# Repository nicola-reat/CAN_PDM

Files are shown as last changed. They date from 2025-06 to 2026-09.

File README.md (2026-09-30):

# CAN PDM – Power Distribution Module
 
A CAN-controlled power distribution module (PDM) designed for a race car. It replaces fuses, relays and dashboard switches with nine protected, current-monitored high-side outputs that are switched from a Blink Marine keypad over CAN.
 
This repository contains everything needed to understand, build and modify the module: firmware, CAN documentation and DBC files, the Altium PCB project with thermal simulations, and the 3D models of the enclosure and bus bar.
 
| MCU | Supply | Outputs | CAN | Firmware |
|:---:|:---:|:---:|:---:|:---:|
| STM32F446RET6 | 12 V | 9 protected channels | 500 kbit/s | STM32 HAL |
 
## Table of contents
 
1. [What it does](#what-it-does)
2. [System overview](#system-overview)
3. [Outputs](#outputs)
4. [Protection](#protection)
5. [Keypad control](#keypad-control)
6. [On-board LEDs](#on-board-leds)
7. [CAN interface](#can-interface)
8. [Running two boards](#running-two-boards)
9. [Repository structure](#repository-structure)
10. [Hardware](#hardware)
11. [Firmware](#firmware)
---
 
## What it does
 
The PDM sits between the battery and the car's electrical loads: fuel pumps, fans, heating, cabin fans, lights and most other consumers. Each load is fed through its own Infineon PROFET smart high-side switch. The microcontroller switches the outputs, measures the current of every channel, and reacts to faults before wiring or loads are damaged.
 
- **Switches nine outputs** on request, from the keypad or from a CAN command frame.
- **Measures current** on every output, plus battery voltage and board temperature.
- **Detects faults** per channel: overcurrent, short circuit, open load and thermal.
- **Sheds load by priority** when the board gets too hot or the battery voltage drops: low-priority outputs go first, then medium, and everything at the critical level.
- **Gives feedback on the keypad**: each button LED shows whether its output is on or off, and blinks in a fault-specific color when the output has failed.
- **Gives feedback on the board**: nine bicolor LEDs, one per output, show the output state and blink in a fault-specific pattern.
- **Reports everything over CAN**: status, currents and fault codes are transmitted every 100 ms for a dashboard or data logger.
## System overview
 
```mermaid
flowchart LR
    BAT["12 V battery"] --> PDM1["PDM_1"]
    BAT --> PDM2["PDM_2"]
    KP["Blink Marine keypad"] --- CAN(["CAN bus, 500 kbit/s"])
    CAN --- PDM1
    CAN --- PDM2
    CAN --- LOG["Dashboard / logger / SavvyCAN"]
    PDM1 --> LOADS1["Pumps, fans, heating, lights..."]
    PDM2 --> LOADS2["Pumps, fans, heating, lights..."]
```
 
A key press is sent by the keypad to the bus. Every PDM receives it and decides, from its own key-to-output mapping, whether one of its outputs is affected. The PDM then confirms the result by updating the LED on the same key and the output's LED on the board.
 
## Outputs
 
Nine outputs, grouped by current capability. Values below are the limits configured in the firmware. They were set to arbitrary, wide-margin values, and only after several tests. They obviously need to be fine-tuned for the actual load. Next planned feature: configuring these parameters over CAN through a GUI.
 
| Group | Outputs | Device | Continuous limit | Startup limit (duration) | Short-circuit threshold | Open-load threshold | Priority |
|---|:---:|---|:---:|:---:|:---:|:---:|:---:|
| High | H1, H2 | BTS7002-1EPP | 21 A | 81 A (1.5 s) | 50 A | 1.0 A | High |
| High | H3 | BTS7002-1EPP | 21 A | 41 A (1.5 s) | 50 A | 0.5 A | High |
| Medium | M1, M2 | BTS7004-1EPZ | 15 A | 40 A (3.0 s) | 40 A | 0.5 A | Medium |
| Low | L1, L2 | BTS7008-2EPZ | 7.5 A | 25 A (2.5 s) | 25 A | 0.5 A | Low |
| Low | L3, L4 | BTS7008-2EPZ | 7.5 A | 15 A (2.5 s) | 15 A | 0.5 A | Low |
 
- Each output has its own continuous limit, a higher startup limit for a set time (loads such as lamps, motors and pumps draw a large inrush current), a short-circuit threshold and an open-load threshold.
- The BTS7008-2EPZ is a dual-channel device: **L1/L2 share one current-sense line and L3/L4 share another**.
- Load current is measured from the PROFET current-sense output: the ADC reads the voltage across a 1.2 kΩ sense resistor, `IIS = V / Rsense`, and the load current is `Iload = IIS × kILIS`, where kILIS is the device's current-sense ratio.
## Protection
 
### Per-channel faults
 
Current-based monitoring runs only while an output is on. While an output is off its current reading is ignored, so ADC noise cannot cause false faults.
 
| Fault | Condition | Result |
|---|---|---|
| Short circuit | Current stays above the short-circuit threshold for at least 50 ms | Output switched off, fault latched |
| Overcurrent | Current exceeds the active limit: the startup limit during the startup time, the continuous limit afterwards | Output switched off immediately, fault latched |
| Open load | Current stays below the open-load threshold for at least 200 ms, checked starting 500 ms after switch-on | Fault reported, output stays on, cleared automatically when the current rises above the threshold |
| Thermal | Thermal fault on the channel | Latched, like short circuit and overcurrent |
 
**Latched faults.** Short circuit, overcurrent and thermal faults are hard faults: the output cannot be switched on again until the fault is reset. Pressing the output's key on the keypad resets the fault and requests the output on. If the cause is still present, the fault is detected again and the output stays faulted until the next reset. Open load is the exception: it is not latched, and it clears by itself once the load draws current again.
 
Faults are shown on the keypad (blinking LED) and reported in the CAN fault messages.
 
### Over-temperature (board temperature)
 
| Level | Threshold | Action | Recovery |
|---|:---:|---|:---:|
| Warning | 70 °C | Reports the `OVERTEMP` state only | – |
| Low priority | 85 °C | Low-priority outputs switched off | 80 °C |
| Medium priority | 95 °C | Medium-priority outputs switched off | 90 °C |
| Critical | 100 °C | All outputs switched off | 95 °C |
 
### Under-voltage (battery voltage)
 
| Level | Threshold | Action | Recovery |
|---|:---:|---|:---:|
| Warning | 11.8 V | Reports the `UNDERVOLTAGE` state only | – |
| Low priority | 11.5 V | Low-priority outputs switched off | 12.0 V |
| Medium priority | 11.2 V | Medium-priority outputs switched off | 11.8 V |
| Critical | 9.5 V | All outputs switched off | 10.5 V |
 
Every level has a **hysteresis**: the recovery threshold is different from the shutdown threshold, so outputs do not turn on and off repeatedly around a limit.
 
- Outputs shed by a thermal or under-voltage shutdown come back **automatically** once the temperature or voltage passes the recovery threshold, as long as they are still requested on.
- The warning levels only change the state reported over CAN. They do not switch anything off. If both warnings are active, `OVERTEMP` takes precedence over `UNDERVOLTAGE`.
- Outputs in a latched fault (see above) are always kept off.
- Priorities are ordered High (1), Medium (2), Low (3). Each shutdown level switches off its own priority and every less important one, so **High-priority outputs are only switched off at the critical level**.
## Keypad control
 
The PDM works with a **Blink Marine CAN keypad**. Each button is associated with one output:
 
- Press a button to **toggle** its output.
- If the output is in fault, pressing the button **resets the fault** and switches the output on again.
- The LED shows the output state: green when on, off when off, and blinking yellow, amber, red or cyan for open load, overcurrent, short circuit and thermal faults.
- The LED state is re-sent every 100 ms, so the keypad recovers if a CAN frame is lost.
- Keypad brightness is set by the PDM at startup.
The key-to-output mapping is different for each board and is listed in the CAN documentation.
 
## On-board LEDs
 
Each output has a bicolor (green/red) LED on the PCB, so its state can be read at a glance without a keypad or a CAN tool. Together with the keypad LEDs and the CAN messages, there are three ways to see what an output is doing.
 
| LED | Meaning |
|---|---|
| Both off | Output off |
| Green, steady | Output on, no fault |
| Red, blinking | Fault on this output (green is off) |
 
The number of red blinks tells which fault it is. The sequence is followed by a one-second pause and then repeats.
 
| Red blinks | Fault |
|:---:|---|
| 1 | Open load |
| 2 | Overcurrent |
| 3 | Short circuit |
| 4 | Thermal |
| 5 | Under-voltage |
 
Example: two blinks, pause, two blinks, pause... means overcurrent.
 
## CAN interface
 
| Parameter | Value |
|---|---|
| Bitrate | 500 kbit/s |
| Status messages | Every 100 ms |
| Byte order | Little-endian |
| Units | A, V, °C |
 
Transmitted messages: PDM status (heartbeat, state, total current, battery voltage, temperature), status and current of every output group, and fault codes for every output. Received messages: the output command and the keypad key frames.
 
The complete reference, with byte layouts and conversion formulas, is in [`FW/Doc/`](FW/Doc/). Ready-to-use DBC files for [SavvyCAN](https://www.savvycan.com/) are in [`FW/Dbc_Database/`](FW/Dbc_Database/).
 
## Running two boards
 
The car uses **two identical PDM boards**. They are not different hardware: `PDM_ID` in the firmware gives each board its own identity.
 
| | PDM_1 | PDM_2 |
|---|:---:|:---:|
| CAN address | `0x30` | `0x31` |
| Status message ID | `0x300` | `0x400` |
| Output messages | `0x301`–`0x313` | `0x401`–`0x413` |
| Command frame | `0x200` | `0x200` |
 
Both boards share the same bus and receive the same keypad frames; each applies its own key-to-output mapping.
 
## Repository structure
 
```
.
├── 3D/                  3D models: bus bar, cover and case
├── Docs/                Pinout of PDM_1 and PDM_2 as installed in the car
├── FW/
│   ├── Doc/             CAN message documentation
│   ├── Dbc_Database/    DBC files for SavvyCAN (one per board)
│   └── can_pdm/         Firmware project
└── PCB/
    ├── 3d/              STEP model of the PCB
    ├── CAN_PDM/         Altium Designer project
    └── thermal analysis/ Thermal simulations
```
 
## Hardware
 
- **PCB:** designed in Altium Designer, project in `PCB/CAN_PDM/`. A STEP model of the assembled board is in `PCB/3d/`.
- **Status LEDs:** nine bicolor LEDs, one per output, driven through a PCAL6524 I/O expander.
- **Thermal analysis:** simulations of the board under load are in `PCB/thermal analysis/`.
- **Mechanical parts:** bus bar, case and cover models are in `3D/`.
- **Pinout:** the current pinout of both boards, as installed in the car, is in `Docs/`.
## Firmware
 
- Microcontroller: **STM32F446RET6**
- Framework: STM32 HAL, CAN1 at 500 kbit/s
- Toolchain: **STM32CubeIDE**. Open `FW/can_pdm/` as a project, build and flash from the IDE.
- Project: `FW/can_pdm/`
- Board selection: set `PDM_ID` (`PDM_1` or `PDM_2`) in the firmware configuration before building. Each board must be flashed with its own identity.
- Protection thresholds (temperature, voltage) and per-channel current limits are defined in `pdm_config`, and can be changed there.
The firmware runs on FreeRTOS with three tasks:
 
| Task | Period | Job |
|---|:---:|---|
| Acquisition | 10 ms | Reads the battery voltage (ADC) and the board temperature (MCP9808 sensor), updates the current of all nine outputs and runs the fault checks |
| Telemetry | 100 ms | Transmits all CAN status, current and fault messages, and updates the keypad LEDs |
| Power manager | 100 ms | Applies the thermal and under-voltage protection, applies the requested state to every output and sets the PDM state |
 
PDM state reported in the CAN status message:
 
| State | When |
|---|---|
| `RUN` | Normal operation |
| `UNDERVOLTAGE` | Battery voltage below 11.8 V |
| `OVERTEMP` | Board temperature above 70 °C (takes precedence over `UNDERVOLTAGE`) |
| `INIT` | Initial value at power-up |
| `FAULT`, `SLEEP` | Defined in the firmware but not set by the power manager |
 
## License
 
This project is open source and released under the [MIT License](LICENSE). You are free to use, modify and share it, as long as the copyright notice is kept.
 
This hardware and firmware control high-current circuits in a vehicle. It is provided as is, with no warranty: build and install it at your own risk.

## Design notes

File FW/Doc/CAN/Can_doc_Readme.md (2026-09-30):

# CAN PDM – CAN Bus Message Reference

Reference for every CAN message received and transmitted by the PDM (Power Distribution Module), including byte layouts and the formulas needed to convert raw hexadecimal data into units (Amperes, Volts, °C).

| Bitrate | Cycle time | Frame length | Byte order | Units |
|:---:|:---:|:---:|:---:|:---:|
| **500 kbit/s** | **100 ms** | **DLC 8** | **Little-endian** | °C · V · A |

## Table of contents

1. [Overview](#1-overview)
2. [How to decode a value](#2-how-to-decode-a-value)
3. [Message list and IDs](#3-message-list-and-ids)
4. [Enumerations](#4-enumerations)
5. [Received messages](#5-received-messages)
6. [Transmitted messages](#6-transmitted-messages)
7. [Blink Marine keypad](#7-blink-marine-keypad)

---

## 1. Overview

The PDM drives nine Profet output channels, grouped by current capability:

| Group | Channels |
|---|---|
| High | H1, H2, H3 |
| Medium | M1, M2 |
| Low | L1, L2, L3, L4 |

Outputs can be switched:

- by a **Blink Marine keypad** (extended CAN frames), or
- by the **`0x200` command frame** (standard CAN frame) Only for bench-testing.

The PDM periodically transmits its own status, per-output currents and fault codes.

**Multiple boards on one bus.** `PDM_1` and `PDM_2` are not different hardware: they are two identical boards installed in the same vehicle. `PDM_ID` is set at compile time to give each board its own identity (CAN address and status IDs), so both can share one bus. The command frame `0x200` uses the same ID on both boards [To Be deleted].

**Legend used in the byte tables**

| Symbol | Meaning |
|:---:|---|
| ⬜ | Counter / heartbeat |
| 🟧 | State or flags |
| 🟩 | Current (A) |
| 🟪 | Voltage (V) |
| 🟥 | Temperature (°C) |
| 🟦 | Output number or key number |
| ⬛ | Reserved / unused |

---

## 2. How to decode a value

16-bit values are sent **LSB first**:

```
value = LSB + (MSB × 256)
```

Then apply the scale factor of the field:

| Quantity | Formula | Resolution |
|---|---|---|
| Current | `value / 10` → A | 0.1 A |
| Battery voltage | `value / 100` → V | 0.01 V |
| Temperature | `value / 100` → °C | 0.01 °C |

Example: bytes `64 00` → `0x0064` = 100 → 100 / 10 = **10.0 A**.

---

## 3. Message list and IDs

Each board takes its identity (`PDM_1` or `PDM_2`) from `PDM_ID`. CAN addresses used for the extended frames:

| Device | CAN address |
|---|:---:|
| Keypad (`KEYPAD_CAN_ADDRESS`) | `0x21` |
| PDM_1 (`PDM_CAN_ADDRESS`) | `0x30` |
| PDM_2 (`PDM_CAN_ADDRESS`) | `0x31` |

### Standard frames (11-bit ID)

| Message | Direction | PDM_1 | PDM_2 | Section |
|---|:---:|:---:|:---:|:---:|
| Output command | RX | `0x200` | `0x200` | [5.1](#51-output-command--0x200) |
| PDM status | TX | `0x300` | `0x400` | [6.1](#61-pdm-status--0x300--0x400) |
| High outputs fault types (H1–H3) | TX | `0x301` | `0x401` | [6.3](#63-fault-types) |
| Medium outputs fault types (M1–M2) | TX | `0x302` | `0x402` | [6.3](#63-fault-types) |
| Low 1 outputs fault types (L1–L2) | TX | `0x303` | `0x403` | [6.3](#63-fault-types) |
| Low 2 outputs fault types (L3–L4) | TX | `0x304` | `0x404` | [6.3](#63-fault-types) |
| High outputs status and currents | TX | `0x310` | `0x410` | [6.2](#62-output-status-and-currents) |
| Medium outputs status and currents | TX | `0x311` | `0x411` | [6.2](#62-output-status-and-currents) |
| Low 1 outputs status and currents | TX | `0x312` | `0x412` | [6.2](#62-output-status-and-currents) |
| Low 2 outputs status and currents | TX | `0x313` | `0x413` | [6.2](#62-output-status-and-currents) |

### Extended frames (29-bit ID, keypad)

| Message | Direction | PDM_1 | PDM_2 | Section |
|---|:---:|:---:|:---:|:---:|
| Key press from keypad | RX | `0x18EFFF21` | `0x18EFFF21` | [7.1](#71-key-press-keypad--pdm) |
| LED command to keypad | TX | `0x18EF2130` | `0x18EF2131` | [7.3](#73-led-command-pdm--keypad) |
| Brightness command to keypad | TX | `0x18EF2130` | `0x18EF2131` | [7.4](#74-brightness-command-pdm--keypad) |

Extended ID format: `0x18EF` + destination address + source address.

> Received frames reach **both** PDMs at the same time. Each PDM interprets them with its own rules: for the keypad, with its own key-to-output mapping ([7.2](#72-key-to-output-mapping)).

---

## 4. Enumerations

### 4.1 Output number (`PDM_Output_t`)

| Value | Output | Group |
|:---:|:---:|---|
| 1 | H1 | High |
| 2 | H2 | High |
| 3 | H3 | High |
| 4 | M1 | Medium |
| 5 | M2 | Medium |
| 6 | L1 | Low |
| 7 | L2 | Low |
| 8 | L3 | Low |
| 9 | L4 | Low |

### 4.2 PDM state (`PDM_State_t`)

| Value | State |
|:---:|---|
| 0 | `PDM_STATE_INIT` |
| 1 | `PDM_STATE_RUN` |
| 2 | `PDM_STATE_FAULT` |
| 3 | `PDM_STATE_OVERTEMP` |
| 4 | `PDM_STATE_UNDERVOLTAGE` |
| 5 | `PDM_STATE_SLEEP` |

### 4.3 Fault type (`ProfetFault_t`)

| Value | Fault | Keypad LED |
|:---:|---|---|
| 0 | `FAULT_NONE` | Follows output state |
| 1 | `FAULT_OVERCURRENT` | Amber/orange, blinking |
| 2 | `FAULT_SHORT_CIRCUIT` | Red, blinking |
| 3 | `FAULT_OPEN_LOAD` | Yellow, blinking |
| 4 | `FAULT_THERMAL` | Cyan, blinking |
| 5 | `FAULT_UNDERVOLTAGE` | No dedicated LED rule |

### 4.4 Keypad LED colors (`KeypadLedColor_t`)

| Value | Color |
|:---:|---|
| `0x00` | Off |
| `0x01` | Red |
| `0x02` | Green |
| `0x03` | Blue |
| `0x04` | Yellow |
| `0x05` | Magenta |
| `0x06` | Cyan |
| `0x07` | White |
| `0x08` | Amber / orange |

### 4.5 Keypad LED modes (`KeypadLedMode_t`)

| Value | Mode |
|:---:|---|
| `0x00` | Off |
| `0x01` | On (steady) |
| `0x02` | Blinking |

---

## 5. Received messages

### 5.1 Output command – `0x200`

Standard frame. Requests an output to be switched on or off.

| Byte 0 | Byte 1 | Byte 2 | Byte 3 | Byte 4 | Byte 5 | Byte 6 | Byte 7 |
|:---:|:---:|:---:|:---:|:---:|:---:|:---:|:---:|
| 🟦 Output | 🟧 State | ⬛ | ⬛ | ⬛ | ⬛ | ⬛ | ⬛ |

| Field | Values |
|---|---|
| Output | 1–9, see [4.1](#41-output-number-pdm_output_t) |
| State | `0` = off, any non-zero value = on |

The PDM does not switch the output directly: it sets the channel's requested state, and the protection logic decides whether to enable it.

Examples:

| Frame data | Effect |
|---|---|
| `01 01 00 00 00 00 00 00` | Turn H1 on |
| `06 00 00 00 00 00 00 00` | Turn L1 off |

> In the firmware, PDM_1 and PDM_2 handle this frame identically (same output numbering, no PDM address check).

The keypad frame `0x18EFFF21` is described in [7.1](#71-key-press-keypad--pdm).

---

## 6. Transmitted messages

All messages below are sent every **100 ms**, DLC 8, little-endian.

### 6.1 PDM status – `0x300` / `0x400`

| Byte 0 | Byte 1 | Byte 2 | Byte 3 | Byte 4 | Byte 5 | Byte 6 | Byte 7 |
|:---:|:---:|:---:|:---:|:---:|:---:|:---:|:---:|
| ⬜ Alive | 🟧 State | 🟩 Current LSB | 🟩 Current MSB | 🟪 Voltage LSB | 🟪 Voltage MSB | 🟥 Temp LSB | 🟥 Temp MSB |

| Bytes | Field | Type | Conversion |
|:---:|---|---|---|
| 0 | Alive heartbeat | `uint8` | Counter, increments each message (0–255, then wraps) |
| 1 | PDM state | `uint8` | See [4.2](#42-pdm-state-pdm_state_t) |
| 2–3 | Total current | `uint16` | `value / 10` → **A** |
| 4–5 | Battery voltage | `uint16` | `value / 100` → **V** |
| 6–7 | PDM temperature | `uint16` | `value / 100` → **°C** |

**Example:** `2A 01 64 00 14 05 C4 09`

| Field | Raw | Result |
|---|:---:|---|
| Heartbeat | `0x2A` | 42 |
| State | `0x01` | RUN |
| Total current | `0x0064` = 100 | **10.0 A** |
| Battery voltage | `0x0514` = 1300 | **13.00 V** |
| Temperature | `0x09C4` = 2500 | **25.00 °C** |

### 6.2 Output status and currents

One message per output group. Byte 0 holds status bits, followed by one 16-bit current per output (`value / 10` → **A**).

#### High outputs – `0x310` / `0x410`

| Byte 0 | Byte 1 | Byte 2 | Byte 3 | Byte 4 | Byte 5 | Byte 6 | Byte 7 |
|:---:|:---:|:---:|:---:|:---:|:---:|:---:|:---:|
| 🟧 Flags | 🟩 H1 LSB | 🟩 H1 MSB | 🟩 H2 LSB | 🟩 H2 MSB | 🟩 H3 LSB | 🟩 H3 MSB | ⬛ |

| Bit | Meaning |
|:---:|---|
| 0 | H1 enabled |
| 1 | H2 enabled |
| 2 | H3 enabled |
| 3 | H1 fault |
| 4 | H2 fault |
| 5 | H3 fault |
| 6–7 | Unused |

#### Medium outputs – `0x311` / `0x411`

| Byte 0 | Byte 1 | Byte 2 | Byte 3 | Byte 4 | Byte 5 | Byte 6 | Byte 7 |
|:---:|:---:|:---:|:---:|:---:|:---:|:---:|:---:|
| 🟧 Flags | 🟩 M1 LSB | 🟩 M1 MSB | 🟩 M2 LSB | 🟩 M2 MSB | ⬛ | ⬛ | ⬛ |

| Bit | Meaning |
|:---:|---|
| 0 | M1 enabled |
| 1 | M2 enabled |
| 2 | M1 fault |
| 3 | M2 fault |
| 4–7 | Unused |

#### Low 1 outputs – `0x312` / `0x412`

| Byte 0 | Byte 1 | Byte 2 | Byte 3 | Byte 4 | Byte 5 | Byte 6 | Byte 7 |
|:---:|:---:|:---:|:---:|:---:|:---:|:---:|:---:|
| 🟧 Flags | 🟩 L1 LSB | 🟩 L1 MSB | 🟩 L2 LSB | 🟩 L2 MSB | ⬛ | ⬛ | ⬛ |

| Bit | Meaning |
|:---:|---|
| 0 | L1 enabled |
| 1 | L2 enabled |
| 2 | L1 fault |
| 3 | L2 fault |
| 4–7 | Unused |

#### Low 2 outputs – `0x313` / `0x413`

| Byte 0 | Byte 1 | Byte 2 | Byte 3 | Byte 4 | Byte 5 | Byte 6 | Byte 7 |
|:---:|:---:|:---:|:---:|:---:|:---:|:---:|:---:|
| 🟧 Flags | 🟩 L3 LSB | 🟩 L3 MSB | 🟩 L4 LSB | 🟩 L4 MSB | ⬛ | ⬛ | ⬛ |

| Bit | Meaning |
|:---:|---|
| 0 | L3 enabled |
| 1 | L4 enabled |
| 2 | L3 fault |
| 3 | L4 fault |
| 4–7 | Unused |

The **fault bit** is set when the channel's fault type is anything other than `FAULT_NONE`. The exact fault is reported in the fault messages ([6.3](#63-fault-types)).

**Example** – ID `0x310`, data `03 2C 01 00 00 00 00 00`:

| Field | Raw | Result |
|---|:---:|---|
| Flags | `0x03` | H1 and H2 enabled, no fault |
| H1 current | `0x012C` = 300 | **30.0 A** |
| H2 current | `0x0000` | **0.0 A** |
| H3 current | `0x0000` | **0.0 A** |

### 6.3 Fault types

One byte per output, containing the fault code from [4.3](#43-fault-type-profetfault_t). Unused bytes are `0`.

| ID (PDM_1) | ID (PDM_2) | Byte 0 | Byte 1 | Byte 2 | Bytes 3–7 |
|:---:|:---:|:---:|:---:|:---:|:---:|
| `0x301` | `0x401` | H1 | H2 | H3 | 0 |
| `0x302` | `0x402` | M1 | M2 | 0 | 0 |
| `0x303` | `0x403` | L1 | L2 | 0 | 0 |
| `0x304` | `0x404` | L3 | L4 | 0 | 0 |

**Example** – ID `0x301`, data `00 03 00 00 00 00 00 00`: H2 reports `FAULT_OPEN_LOAD`; H1 and H3 have no fault.

---

## 7. Blink Marine keypad

The keypad uses J1939-style extended frames (`0x18EF` + destination + source), addresses listed in [section 3](#3-message-list-and-ids).

### 7.1 Key press (keypad → PDM)

**ID `0x18EFFF21`** – destination `0xFF` (broadcast), source `0x21` (keypad). Received by both PDMs.

| Byte 0 | Byte 1 | Byte 2 | Byte 3 | Byte 4 | Byte 5 | Byte 6 | Byte 7 |
|:---:|:---:|:---:|:---:|:---:|:---:|:---:|:---:|
| ⬛ | ⬛ | ⬛ | 🟦 Key number | 🟧 Pressed | ⬛ | ⬛ | ⬛ |

| Field | Values |
|---|---|
| Key number | Key ID, see mapping below |
| Pressed | `1` = pressed, `0` = released |

Behavior on a **press edge**:

- If the associated output is in fault → the fault is reset and the output is requested **on**.
- Otherwise → the output **toggles** (on ↔ off).

### 7.2 Key-to-output mapping

Each PDM uses its own mapping. `30` is a placeholder meaning "no key assigned".

| Output | PDM_1 key | PDM_2 key |
|:---:|:---:|:---:|
| H1 | 8 | 6 |
| H2 | 14 | 7 |
| H3 | 10 | 30 (unassigned) |
| M1 | 3 | 13 |
| M2 | 2 | 30 (unassigned) |
| L1 | 1 | 1 |
| L2 | 30 (unassigned) | 5 |
| L3 | 30 (unassigned) | 30 (unassigned) |
| L4 | 30 (unassigned) | 30 (unassigned) |

> ⚠️ If the keypad has a real key numbered 30, pressing it would toggle **all** outputs mapped to 30 at the same time.

### 7.3 LED command (PDM → keypad)

**ID** `0x18EF0000 | (KEYPAD_CAN_ADDRESS << 8) | PDM_CAN_ADDRESS`

| PDM | ID |
|:---:|:---:|
| PDM_1 | `0x18EF2130` |
| PDM_2 | `0x18EF2131` |

| Byte 0 | Byte 1 | Byte 2 | Byte 3 | Byte 4 | Byte 5 | Byte 6 | Byte 7 |
|:---:|:---:|:---:|:---:|:---:|:---:|:---:|:---:|
| `0x04` | `0x1B` | `0x01` | 🟦 Key number | 🟩 Color | 🟪 Mode | `0xFF` | `0xFF` |

Colors: see [4.4](#44-keypad-led-colors-keypadledcolor_t). Modes: see [4.5](#45-keypad-led-modes-keypadledmode_t).

LED behavior, in priority order:

| Condition | Color | Mode |
|---|---|---|
| `FAULT_OPEN_LOAD` | Yellow | Blinking |
| `FAULT_OVERCURRENT` | Amber / orange | Blinking |
| `FAULT_SHORT_CIRCUIT` | Red | Blinking |
| `FAULT_THERMAL` | Cyan | Blinking |
| Output enabled | Green | On |
| Output disabled | Green | Off |

The command is sent when the LED state or mode changes, and **re-sent every 100 ms** otherwise, so the keypad recovers if a frame is lost.

### 7.4 Brightness command (PDM → keypad)

Same ID as the LED command.

| Byte 0 | Byte 1 | Byte 2 | Byte 3 | Byte 4 | Byte 5 | Byte 6 | Byte 7 |
|:---:|:---:|:---:|:---:|:---:|:---:|:---:|:---:|
| `0x04` | `0x1B` | `0x02` | 🟧 Brightness | `0xFF` | `0xFF` | `0xFF` | `0xFF` |

Brightness byte = `percent × 63 / 100` (0 % → `0x00`, 100 % → `0x3F`). The PDM sets 100 % at startup.

---

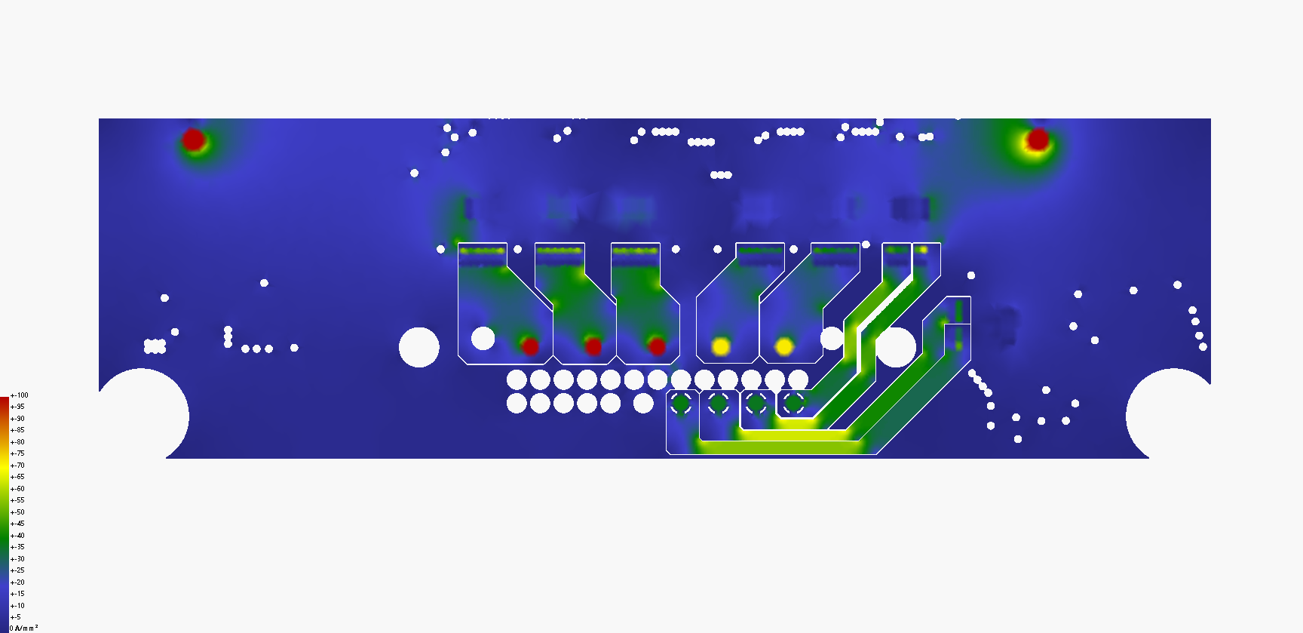
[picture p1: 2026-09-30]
PCB/Thermal_analysis/DC_DROP_CURRENT_DENSITY_BOTTOM.png

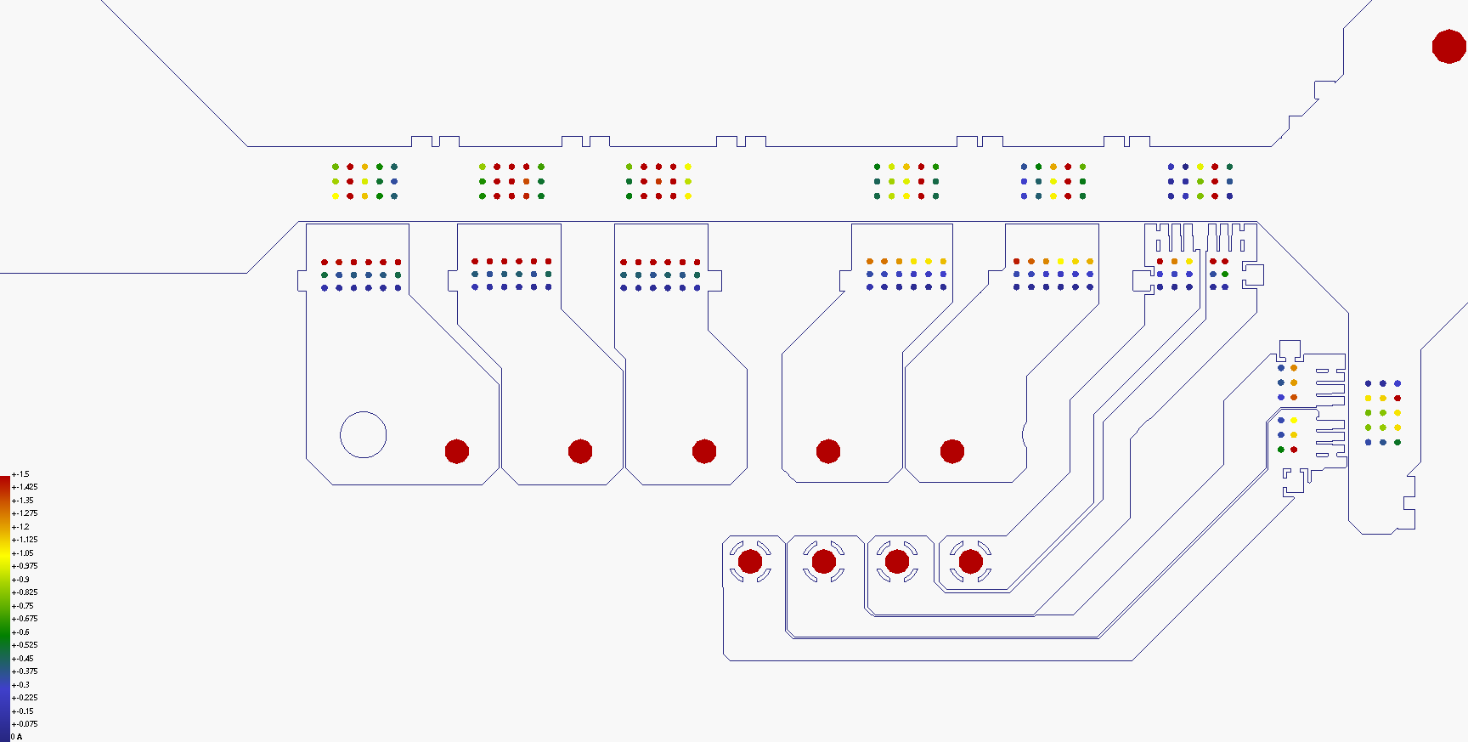
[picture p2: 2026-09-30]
PCB/Thermal_analysis/DC_DROP_VIA_CURRENT.png

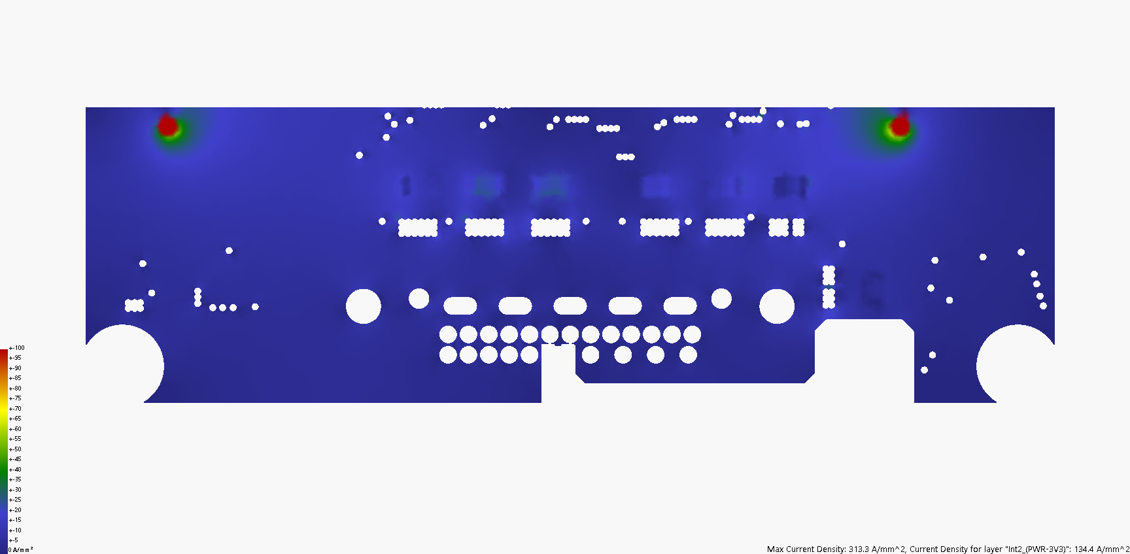
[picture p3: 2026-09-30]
PCB/Thermal_analysis/DC_DROP_CURRENT_DENSITY_IN.png

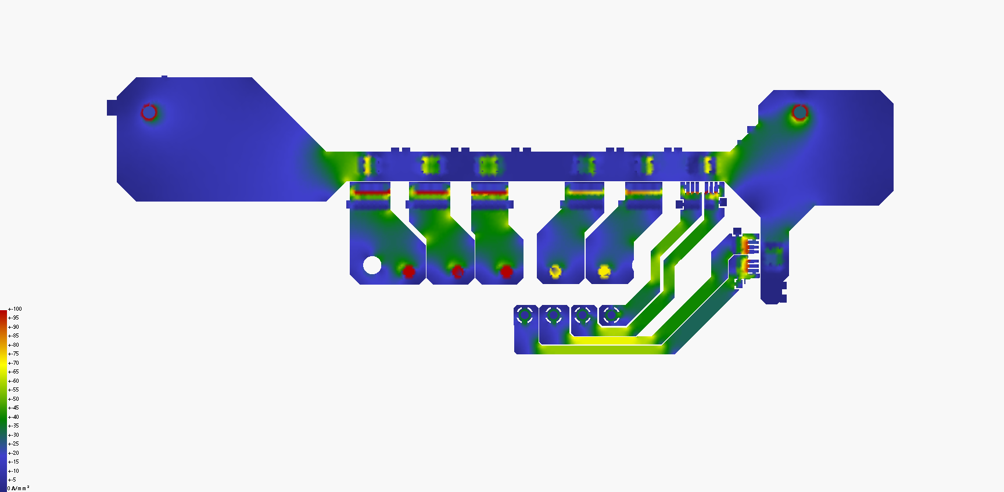
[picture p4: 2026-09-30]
PCB/Thermal_analysis/DC_DROP_CURRENT_DENSITY_TOP.png

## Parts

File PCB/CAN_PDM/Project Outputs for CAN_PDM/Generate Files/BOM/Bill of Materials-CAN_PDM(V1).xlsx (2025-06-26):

 | Bill of Materials |  |  | NR DEVS
Project Title: | Bill of Materials for Variant [V1] of Project [CAN_PDM.PrjPcb] (No PCB Document Selected)
Project File Name: | CAN_PDM.PrjPcb
Assembly Variant: | V1
Designator | Manufacturer | Manufacture Part Number | Footprint | PART-DB Part Number | Quantity
Designator | Manufacturer | PartNumber | Footprint |  | Quantity
C1 | KEMET | C1206C225K5RAC | CAPC3216X16M |  | 1
C2, C10, C12, C14, C16, C17, C21, C23, C24, C25, C27, C28, C30, C34, C38, C42, C47, C48, C51, C52, C57, C58, C62, C67, C72 | KEMET | C0603C104K5RACTU | CAPC1608X09M |  | 25
C3, C4, C5, C6, C9, C11, C13, C15 | Samsung Electro-Mechanics | CL31B106KBHNNNE | CAPC3216X16M |  | 8
C7, C8, C18, C59, C60 | KEMET | C0603C105K8RACTU | CAPC1608X09M |  | 5
C19, C20 | YAGEO | CC0603FRNPO0BN270 | CAPC1608X09M |  | 2
C22 | KEMET | C1206C475K5RACTU | CAPC2012X14N |  | 1
C26 | YAGEO | CC0603KRX7R9BB473 | CAPC1608X09M |  | 1
C29, C33, C37, C41, C61, C66, C71 | KEMET | C0603C473M5RACTU | CAPC1608X09M |  | 7
C31, C35, C39, C43, C63, C64, C68, C69, C73 | KEMET | C0603C103M5RACTM | CAPC1608X09M |  | 9
C32, C36, C40, C44, C65, C70, C74 | KEMET | C0603C221J5RACTU | CAPC1608X09M |  | 7
C53, C54, C55, C56 | KEMET | C0603C103K1RACTU | CAPC1608X09M |  | 4
D1, D2 | Nexperia | PMEG4010EGWX | SODFL360X130-2M -AC |  | 2
D3 | Littelfuse | SZ1SMB20CAT3G | ONSC-SMB-2 |  | 1
D4, D6, D7, D8, D9, D11, D12, D14 | Nexperia | BZX84W-C4V7-QX | SOT65P210X100-3N - AC |  | 8
D5, D13 | Littelfuse | SM712-02HTG | SOT95P240X120-3N |  | 2
D10 | Littelfuse | SP0504BAHTG | SOT95P280X145-5N |  | 1
DL1, DL2 | Wurth Elektronik | 150060GS75000 | LED0603 |  | 2
DL3 | Wurth Elektronik | 150060BS75000 | LED0603 |  | 1
DL4, DL6 | Wurth | 150141YB73100 | WURTH-SBTW_3528 |  | 2
DL5 | Wurth Elektronik | 150060RS75000 | LED0603 |  | 1
DL7, DL8, DL9, DL10, DL11, DL12, DL13, DL14, DL15 | Wurth | 150141RV73100 | WURTH-SBTW_3528 |  | 9
DL16, DL17, DL18, DL19 | Wurth Elektronik | 150060BS55040 | LED0603 |  | 4
J1 | Samtech | FTSH-105-01-L-DV-007-K | SAMTEC_FTSH-105-X-X-DV-007-P-X |  | 1
J2 | Molex | 477450100 | MOLEX_0477450100 |  | 1
J3 | GCT | USB4105-GF-A | GCT-USB4105-GF-A |  | 1
L1 | BOURNS | SDE0805A-180M | BOURNS_SDE0805A |  | 1
L2 | TDK | MMZ1608R601ATD25 | INDC1608X09N |  | 1
L3, L4 | Murata | BLM18HB331SN1D | INDC1608X09N |  | 2
MP1, MP2 | Wurth Electronics | 74651195R | WURTH_74651195 |  | 2
R1 | Vishay | CRCW060388K7FKEAC | RESC1608X06M |  | 1
R2, R16, R17, R100, R101, R124, R125, R126, R127, R128, R129, R130, R131, R132, R133, R134, R135, R136, R137, R138, R139, R140, R141 | Vishay | RC0603FR-071K3L | RESC1608X06M |  | 23
R3, R4, R9, R14, R15, R18, R19, R32, R33, R46, R47, R58, R59, R62, R63, R74, R75, R78, R79, R86, R87, R102, R103, R104, R113, R114, R115, R152 | YAGEO | AC0603FR-0710KL | RESC1608X06M |  | 28
R5 | Vishay | CRCW060322K1FKEA | RESC1608X06M |  | 1
R6, R8, R99, R142, R143, R144, R145 | Vishay | RC0603FR-07560RL | RESC1608X06M |  | 7
R7, R11, R54, R55, R70, R71, R146, R147 | YAGEO | RC0603JR-070RL | RESC1608X06M |  | 8
R10 | Vishay | CRCW060351K0FKEA | RESC1608X06M |  | 1
R12 | Vishay | CRCW06037K50FKEA | RESC1608X06M |  | 1
R13 | Vishay | CRCW0603120RFKEA | RESC1608X06M |  | 1
R20, R26, R34, R40, R105, R116, R153 | Vishay | CRCW080547R0FKEA | RESC2012X06N |  | 7
R21, R22, R23, R24, R27, R28, R29, R30, R35, R36, R37, R38, R41, R42, R43, R44, R80, R81, R82, R83, R88, R89, R90, R91, R106, R107, R108, R109, R110, R111, R117, R118, R119, R120, R121, R122, R154, R155, R156, R157 | YAGEO | RC0603FR-074K7L | RESC1608X06M |  | 40
R25, R31, R39, R45, R112, R123, R158 | Vishay | CRCW06031K20FKEA | RESC1608X06M |  | 7
R52, R53, R56, R57, R68, R69, R72, R73 | Vishay | CRCW060315K0FKEC | RESC1608X06M |  | 8
R94, R95 | Vishay | CRCW06034K70FKEB | RESC1608X06M |  | 2
R96, R97 | Vishay | CRCW060310K0FKEA | RESC1608X06M |  | 2
R98 | Vishay | CRCW06030000Z0EAC | RESC1608X06M |  | 1
R148, R149, R150, R151 | Vishay | CRCW06035K10FKEC | RESC1608X06M |  | 4
SW1 | Nidec Components | CJS-1200TA | SW_CJS-1200TA |  | 1
TP1, TP2, TP3, TP4, TP5, TP6, TP7, TP8, TP9, TP12, TP13, TP14, TP15, TP16, TP19, TP20, TP21, TP22, TP24 |  |  | TP_c200 |  | 19
U1 | Texas Instruments | LV3842XDBVR | SOT95P280X145-6N |  | 1
U2 | Texas Instruments | TLV75533PDBVR | SOT95P280X145-5N |  | 1
U3 | ST | STM32F446RET6 | STM-LQFP64_M |  | 1
U4 | NXP Semiconductors | TJA1051TK/3,118 | SON65P300X300X100-9N-D |  | 1
U5, U6, U18 | Infineon Technologies | BTS70021EPPXUMA1 | SOP65P600X115-15 |  | 3
U7, U8 | Infineon Technologies | BTS70041EPZXUMA1 | SOP65P600X115-15 |  | 2
U9, U10, U11, U12 | Texas Instrument | TLV9001IDBVR | SOT95P280X145-5N |  | 4
U13 | Infineon Technologies | FM24CL16B-GTR | SOIC127P600X175-8N |  | 1
U14 | NXP Semiconductors | PCAL6524HEAZ | FP-SOT1426-1-IPC_A |  | 1
U15 | Microchip | MCP9808-E/MS | MCHP-MSOP-MS8_N |  | 1
U16 | Infineon Technologies | BTS70082EPZXUMA1 | SOP65P600X115-15 |  | 1
U17 | Infineon Technologies | BTS70802EPAXUMA1 | SOP65P600X115-15 |  | 1
X1 | Abracom | ABM8AIG-8.000MHZ-1Z-T | ABM8G_abracon |  | 1
 |  |  |  |  | 293
Notes

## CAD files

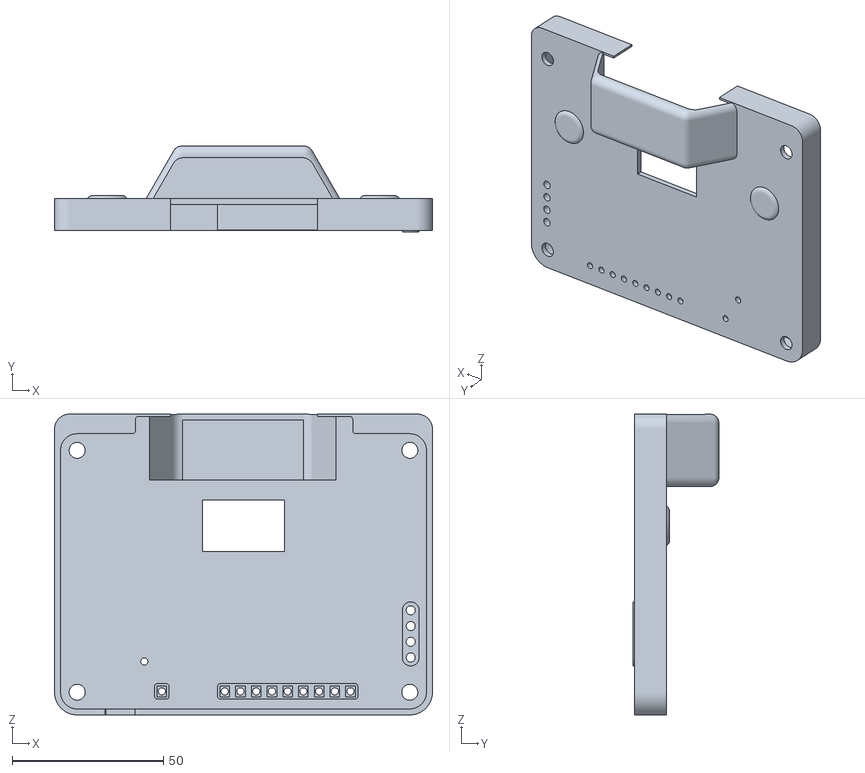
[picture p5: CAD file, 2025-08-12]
3D/Cover.stl
125.0 x 28.4 x 99.5

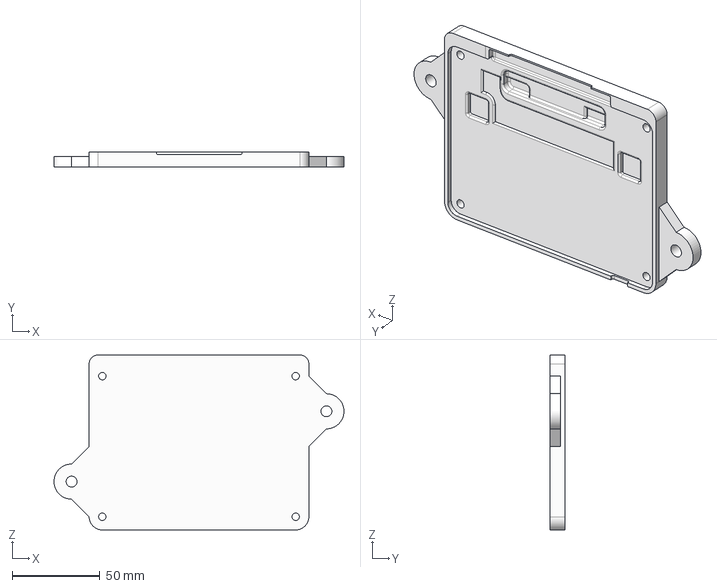
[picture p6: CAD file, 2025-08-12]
3D/BOX.step
165.0 x 8.54 x 99.5 mm

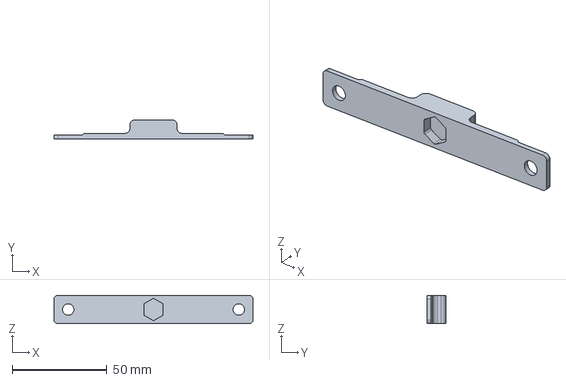
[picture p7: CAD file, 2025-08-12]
3D/BusBar.step
105.0 x 10.0 x 15.0 mm

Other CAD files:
PCB/CAN_PDM/Project Outputs for CAN_PDM/Generate Files/AutoCAD PCB/CAN_PDM_Pcb.DWG

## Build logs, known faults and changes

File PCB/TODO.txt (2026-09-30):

TO DO Schematic:

TO DO PCB:

NOTE:

ASSORBIMENTI:

Assorbimenti 3V3:  366mA --> TPS7A21-Q1 (0.5A max)
Micro: 240mA (Max)
Can: 70mA (tx) --> 10ma (rx)
Flash: 90uA 
Led stato (Verde OK -- Rosso PROBLEMA) : 30 mA (15mA cad)
Sensori temperatura : valori nell'ordine dei uA

Assorbimenti 5V : 150mA  --> LMR51606XDBVR (0.6A max)
9 led stato OK / ERR USCITE : 90 mA (10mA cad)
4 Led Stato Sensori OK / ERR : 40mA (10mA cad) --> Stato sensori per vedere che non siano fuori soglia , Abilitati , Disabilitati ecc
2 Led Stato CAN Tx e CAN Rx : 20mA (10mA cad) --> Stato traffico can

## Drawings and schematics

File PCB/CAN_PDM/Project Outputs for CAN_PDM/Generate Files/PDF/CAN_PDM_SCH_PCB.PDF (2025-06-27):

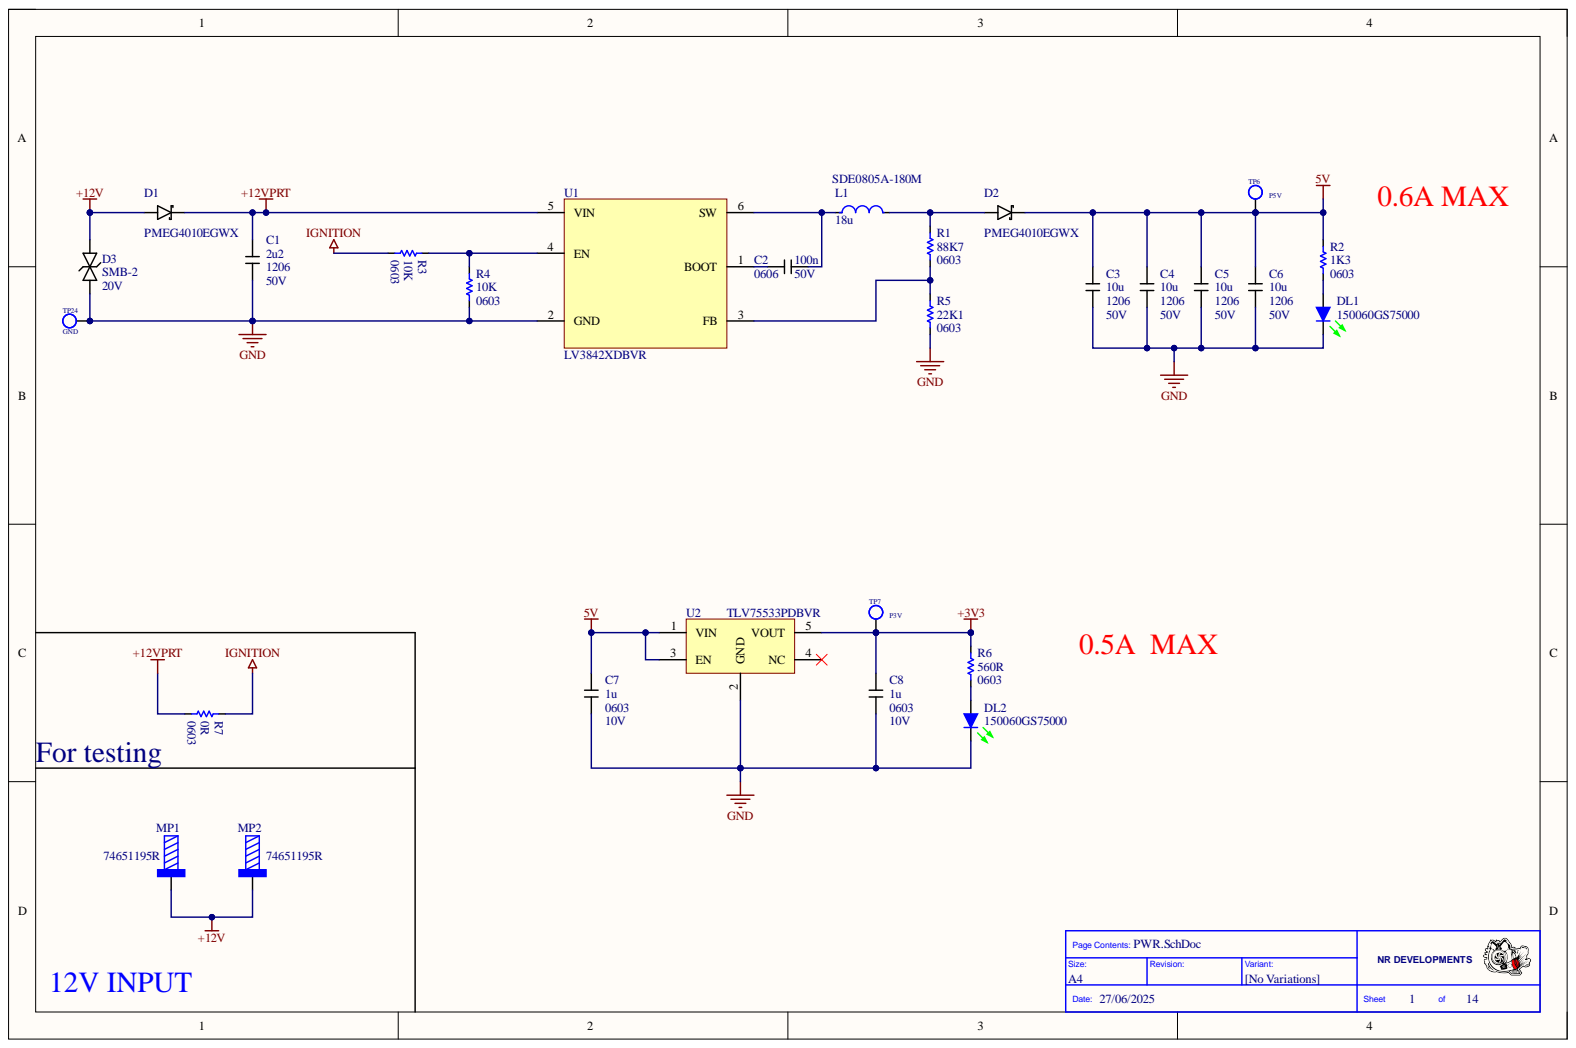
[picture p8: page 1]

Page Contents: PWR.SchDoc

Size: A4 | Revision: | [No Variations] | NR DEVELOPMENTS Variant:

Date: 27/06/2025 | Sheet 1 of 14

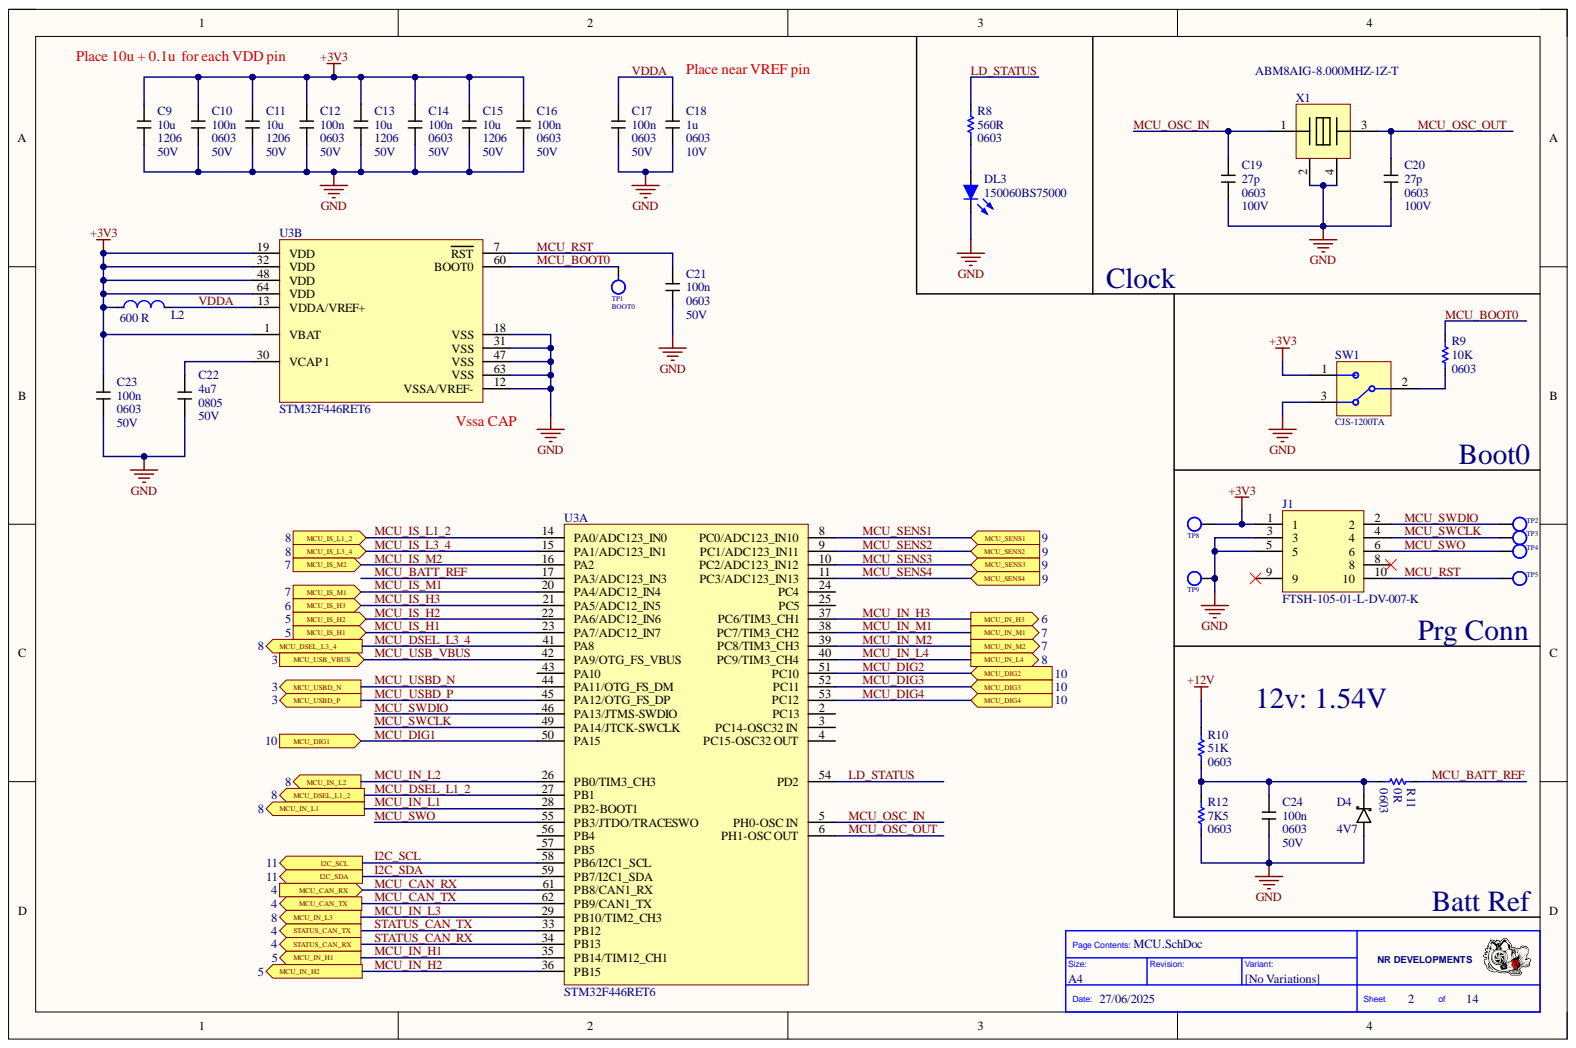
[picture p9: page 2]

1 0 u + 0.1 u fo r each V D D p i n + 3 V 3 100 n V 3 | LD_S TATU S S750 0 0 | ABM8AIG-8.000M HZ -1 Z -T X 1 Cloc k

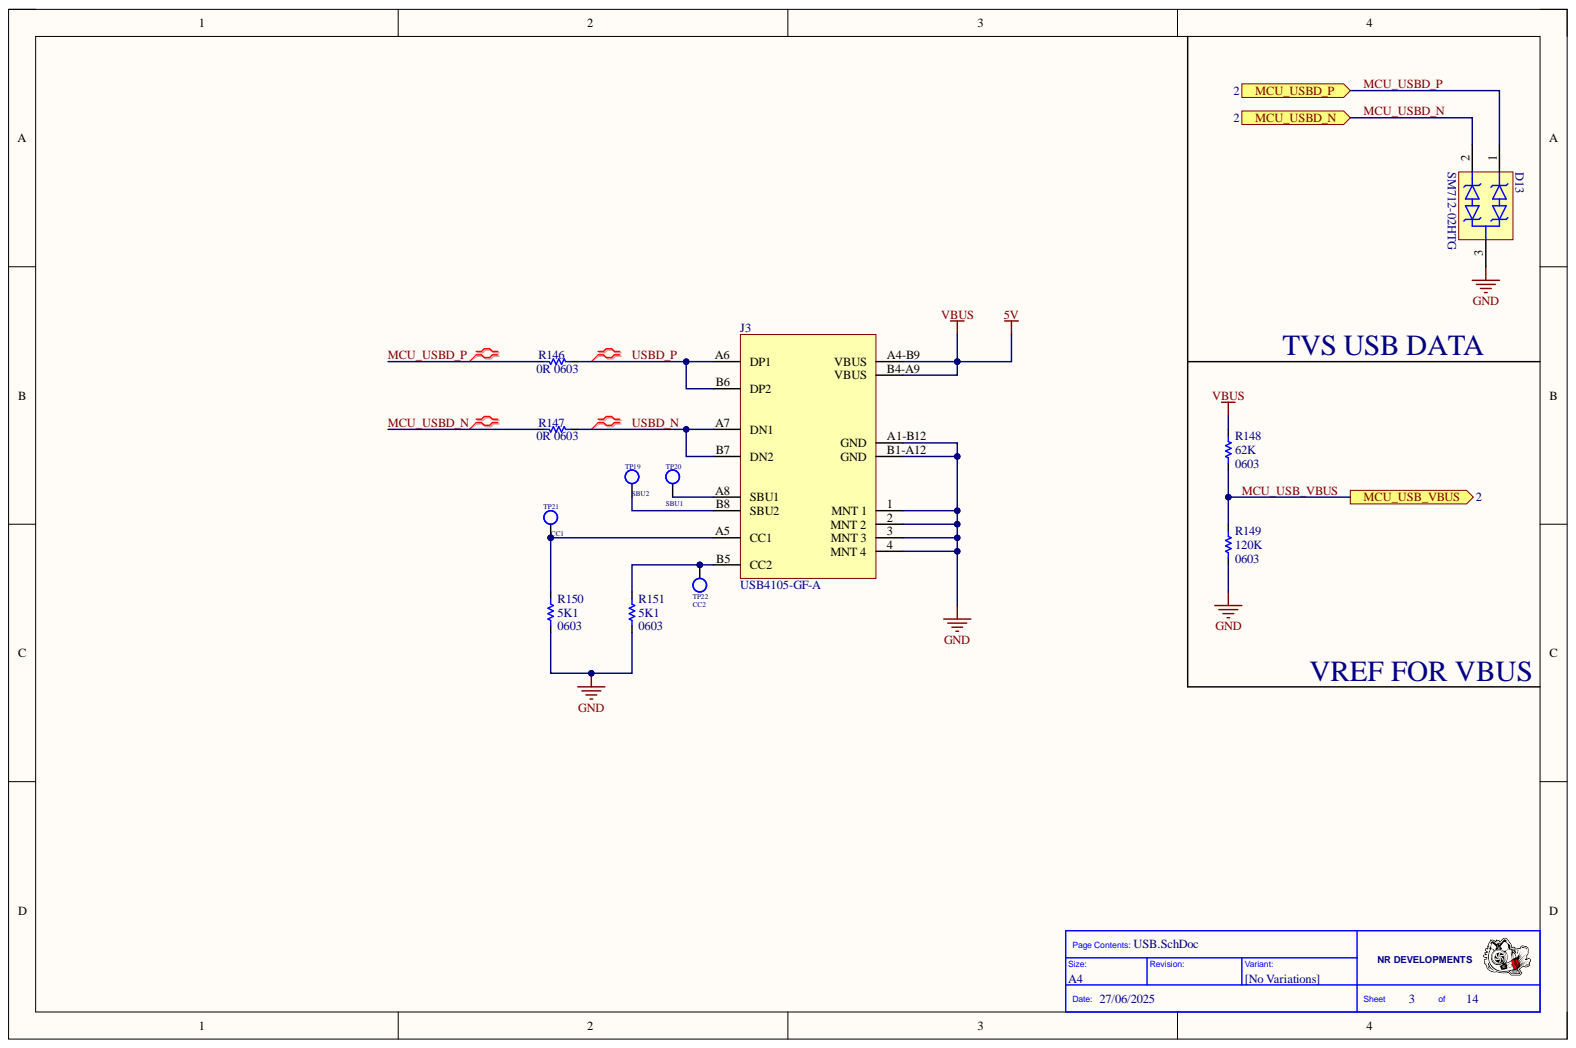
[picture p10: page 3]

Page Contents: USB.SchDoc

Size: A4 | Revision: | [No Variations] | NR DEVELOPMENTS Variant:

Date: 27/06/2025 | Sheet 3 of 14

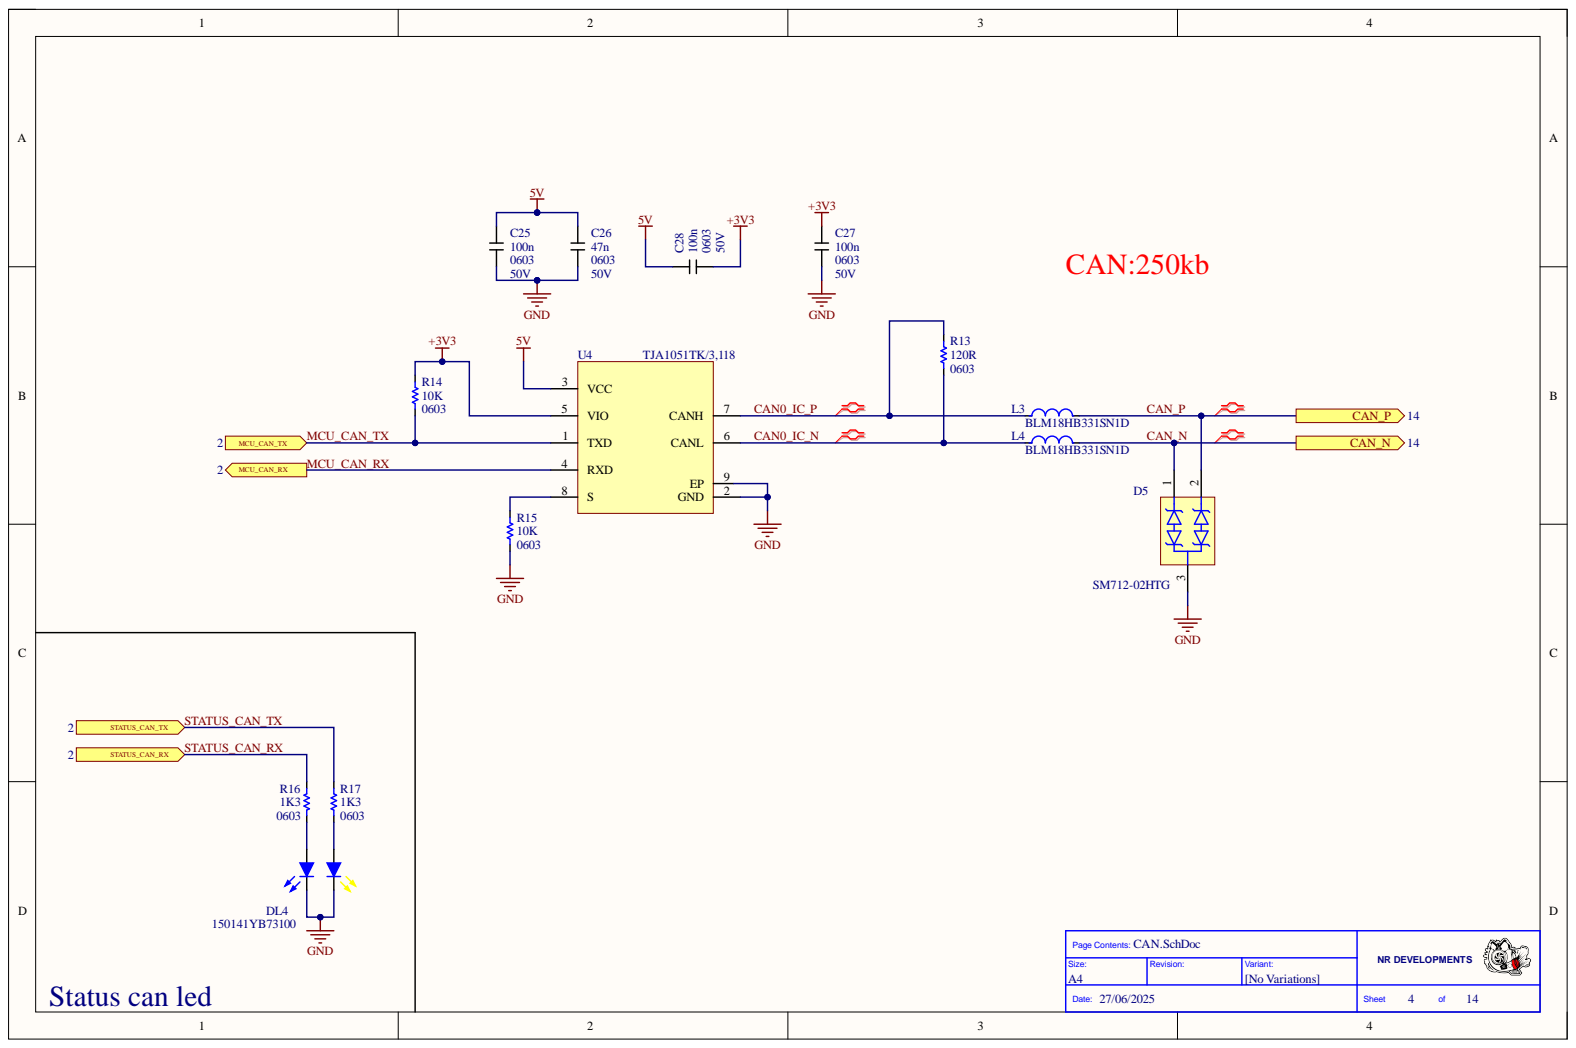
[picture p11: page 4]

Page Contents: CAN.SchDoc

Size: A4 | Revision: | [No Variations] | NR DEVELOPMENTS Variant:

Date: 27/06/2025 | Sheet 4 of 14

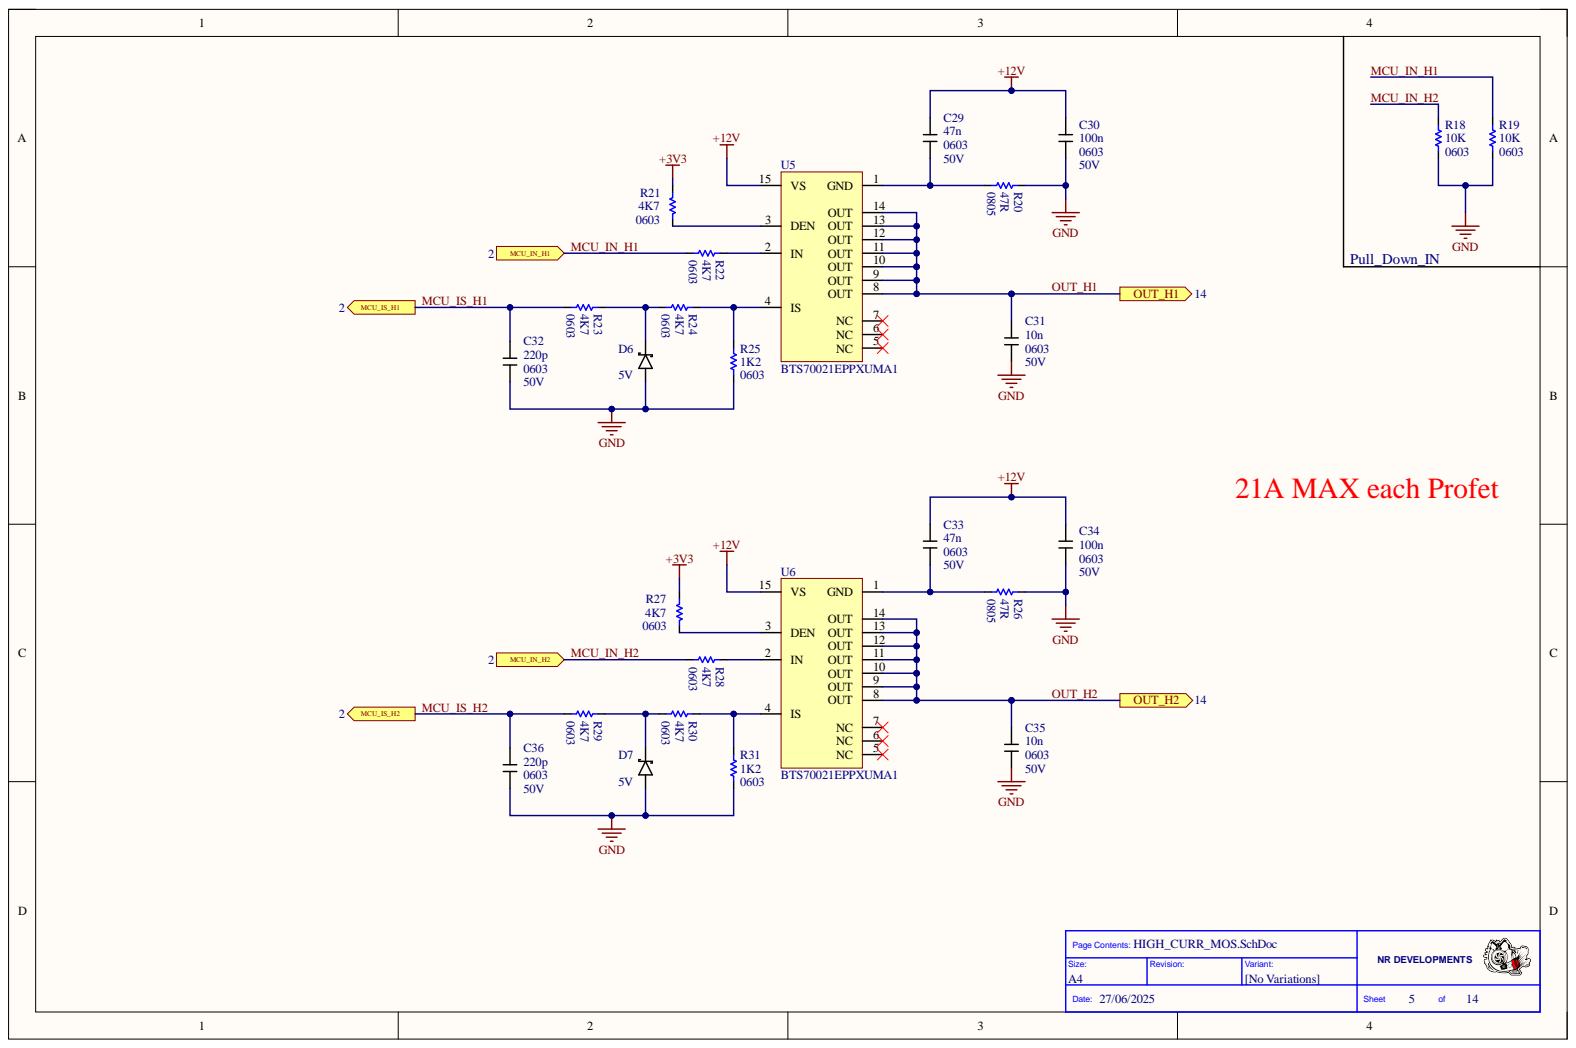
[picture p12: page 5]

Page Contents: HIGH_CUR R_MOS . S c hD o c | N R D E V E L O P M E N T S

Size : A4 | Revision : | Variant : [No Va riation s ]

Date : 27/06/20 2 5 | Shee t 5 of 14

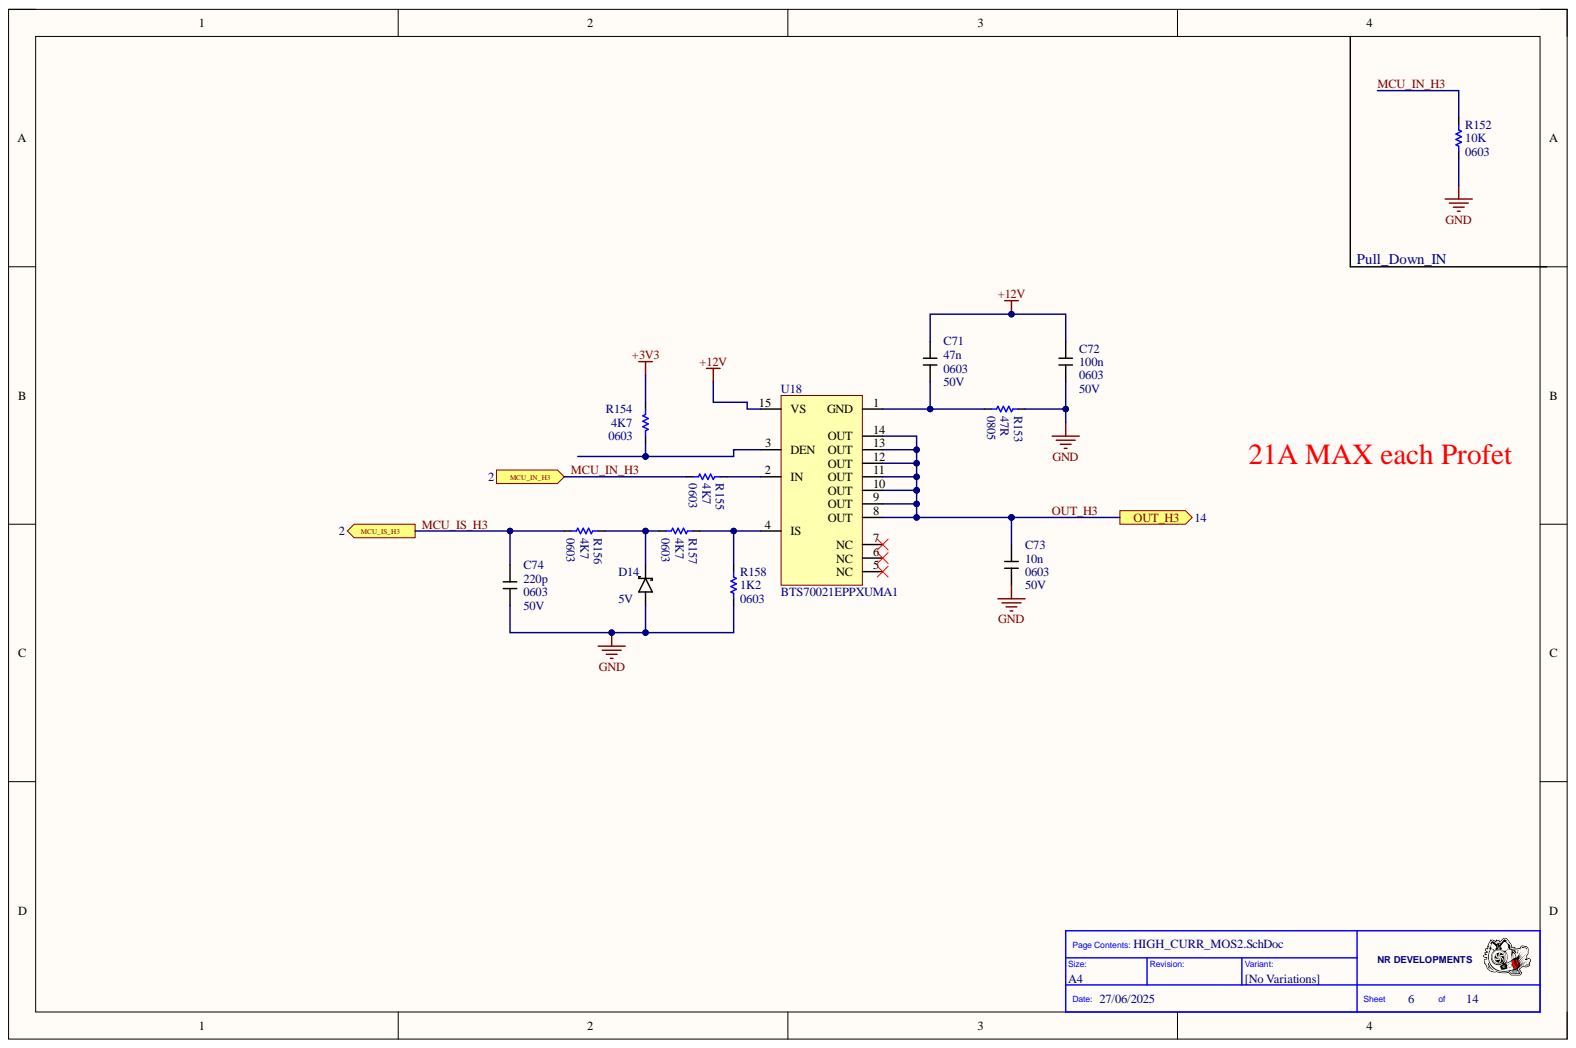
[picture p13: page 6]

Page Contents: HIGH_CURR_MOS2.SchDoc

Size: A4 | Revision: | [No Variations] | NR DEVELOPMENTS Variant:

Date: 27/06/2025 | Sheet 6 of 14

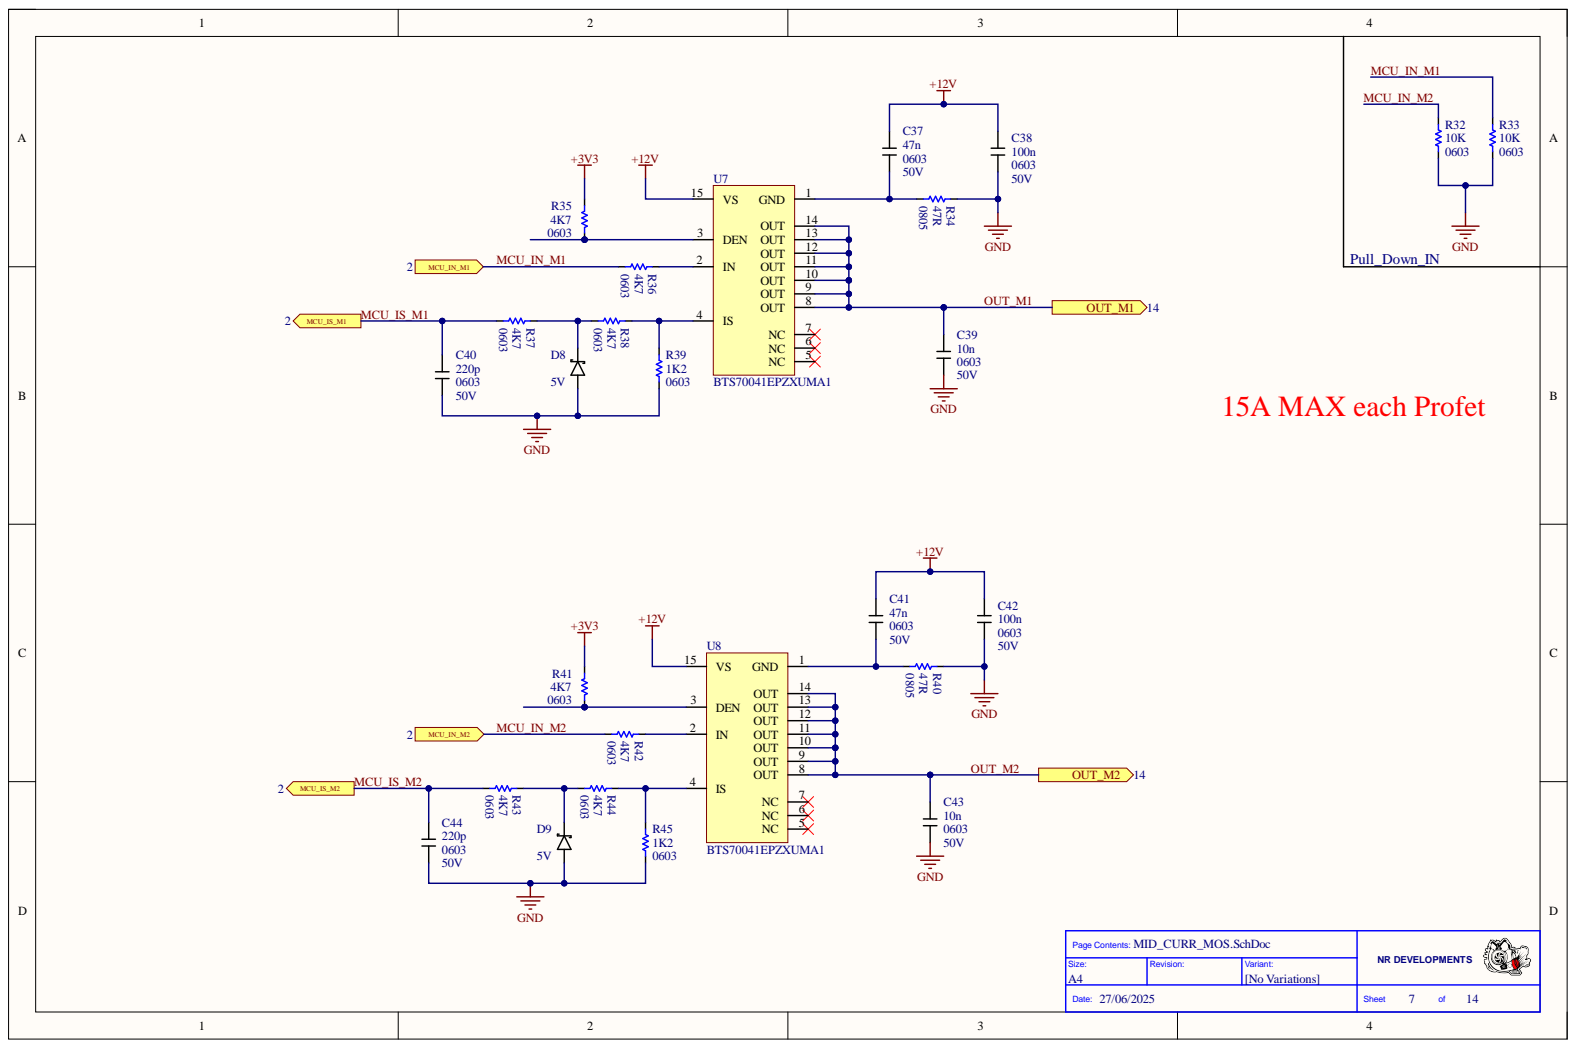
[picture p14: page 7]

Page Contents: MID_CURR_MOS.SchDoc

Size: A4 | Revision: | [No Variations] | NR DEVELOPMENTS Variant:

Date: 27/06/2025 | Sheet 7 of 14

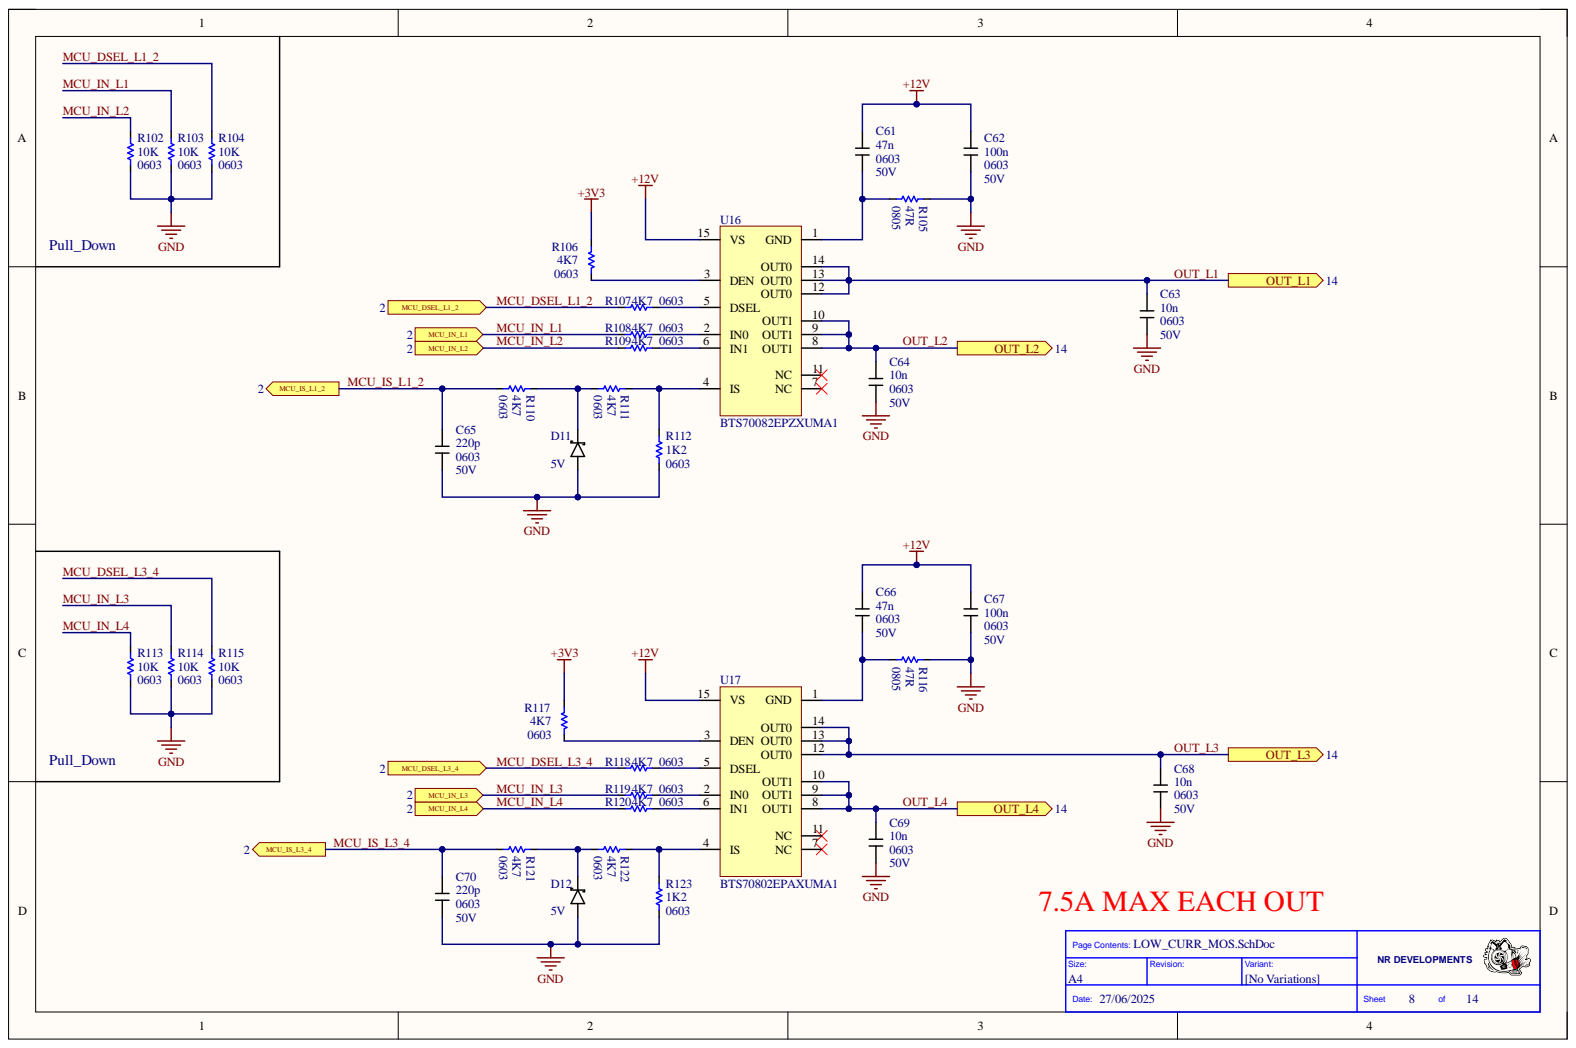
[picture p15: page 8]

Page Contents: LOW_CURR_MOS.SchDoc

Size: A4 | Revision: | [No Variations] | NR DEVELOPMENTS Variant:

Date: 27/06/2025 | Sheet 8 of 14

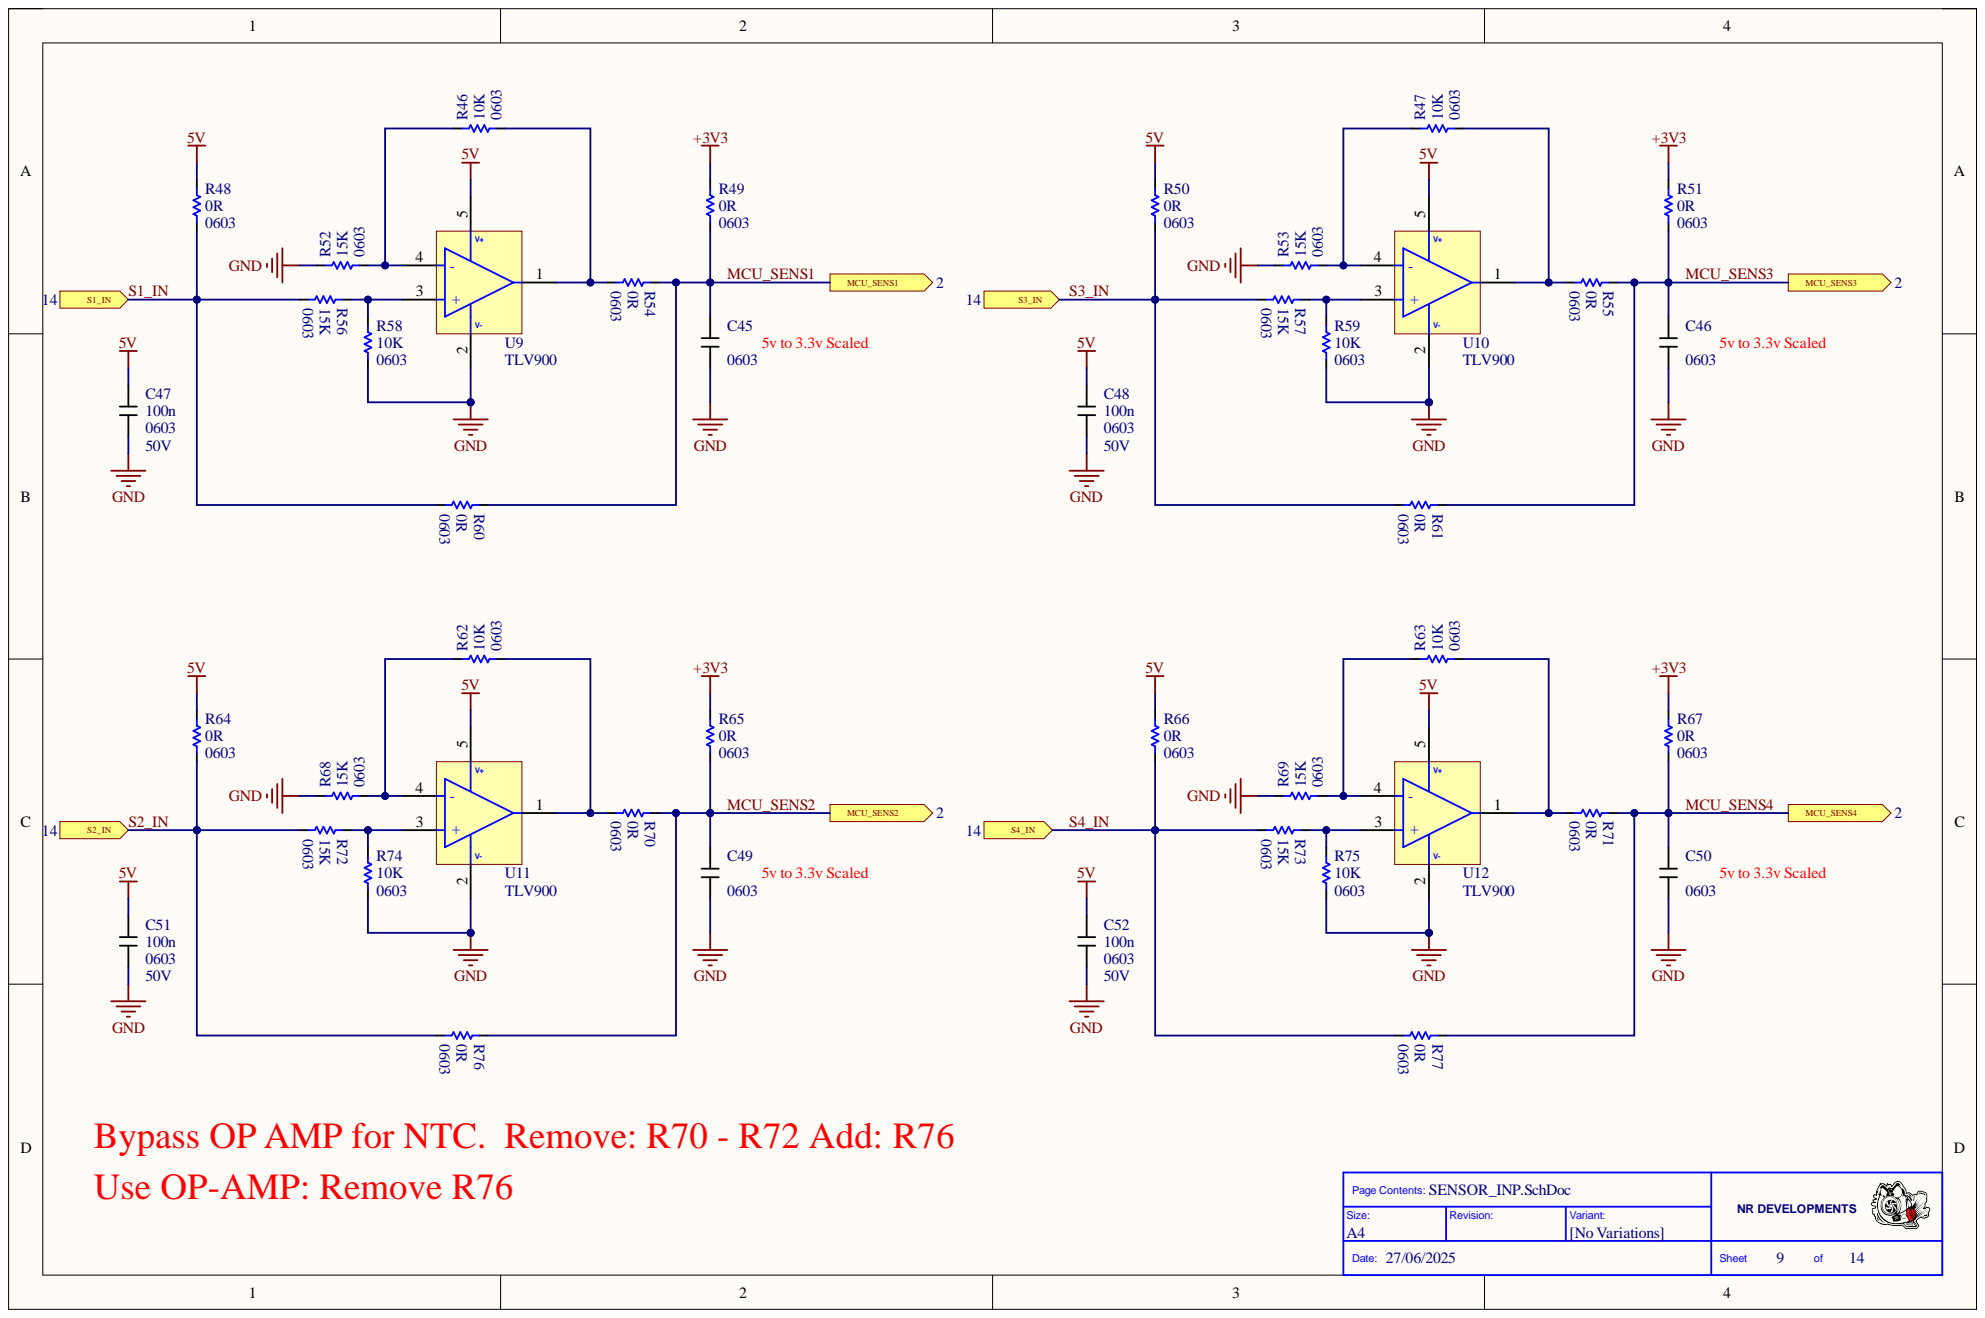
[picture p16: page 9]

Bypass OP AMP for NTC. Remove: R70 - R72 Add: R76
Use OP-AMP: Remove R76

Page Contents: SENSOR_INP.SchDoc

Size: A4 | Revision: | [No Variations] | NR DEVELOPMENTS Variant:

Date: 27/06/2025 | Sheet 9 of 14

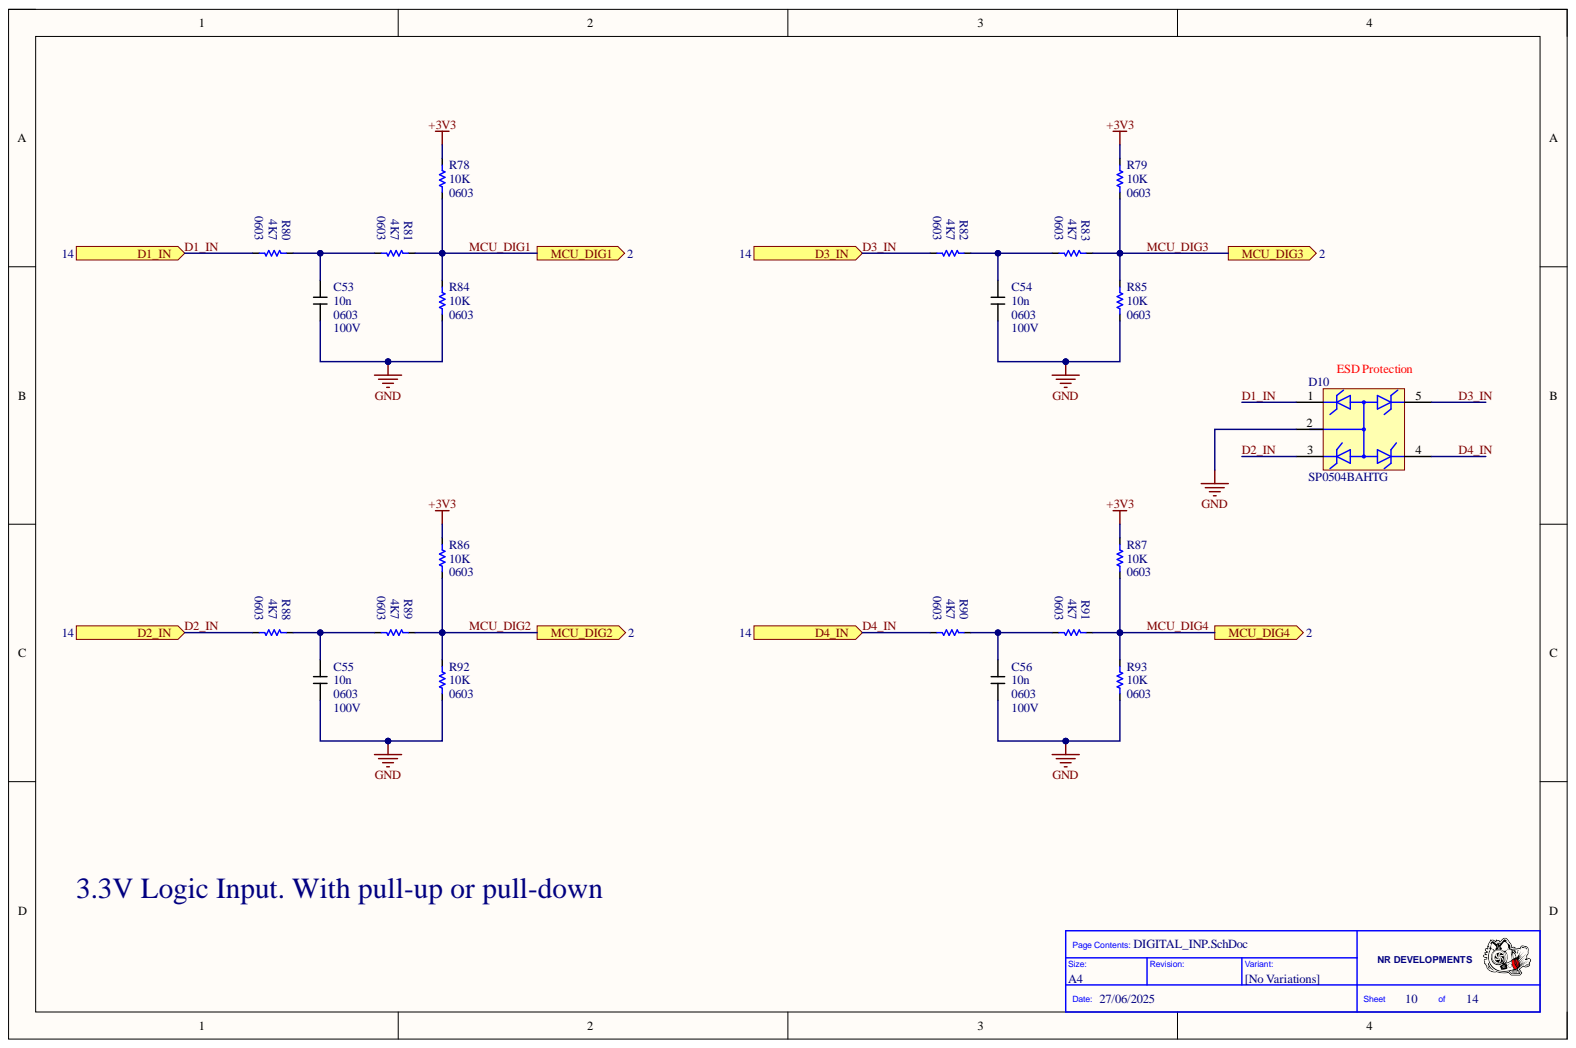
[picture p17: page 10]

3.3V Logic Input. With pull-up or pull-down

Page Contents: DIGITAL_INP.SchDoc

Size: A4 | Revision: | [No Variations] | NR DEVELOPMENTS Variant:

Date: 27/06/2025 | Sheet 10 of 14

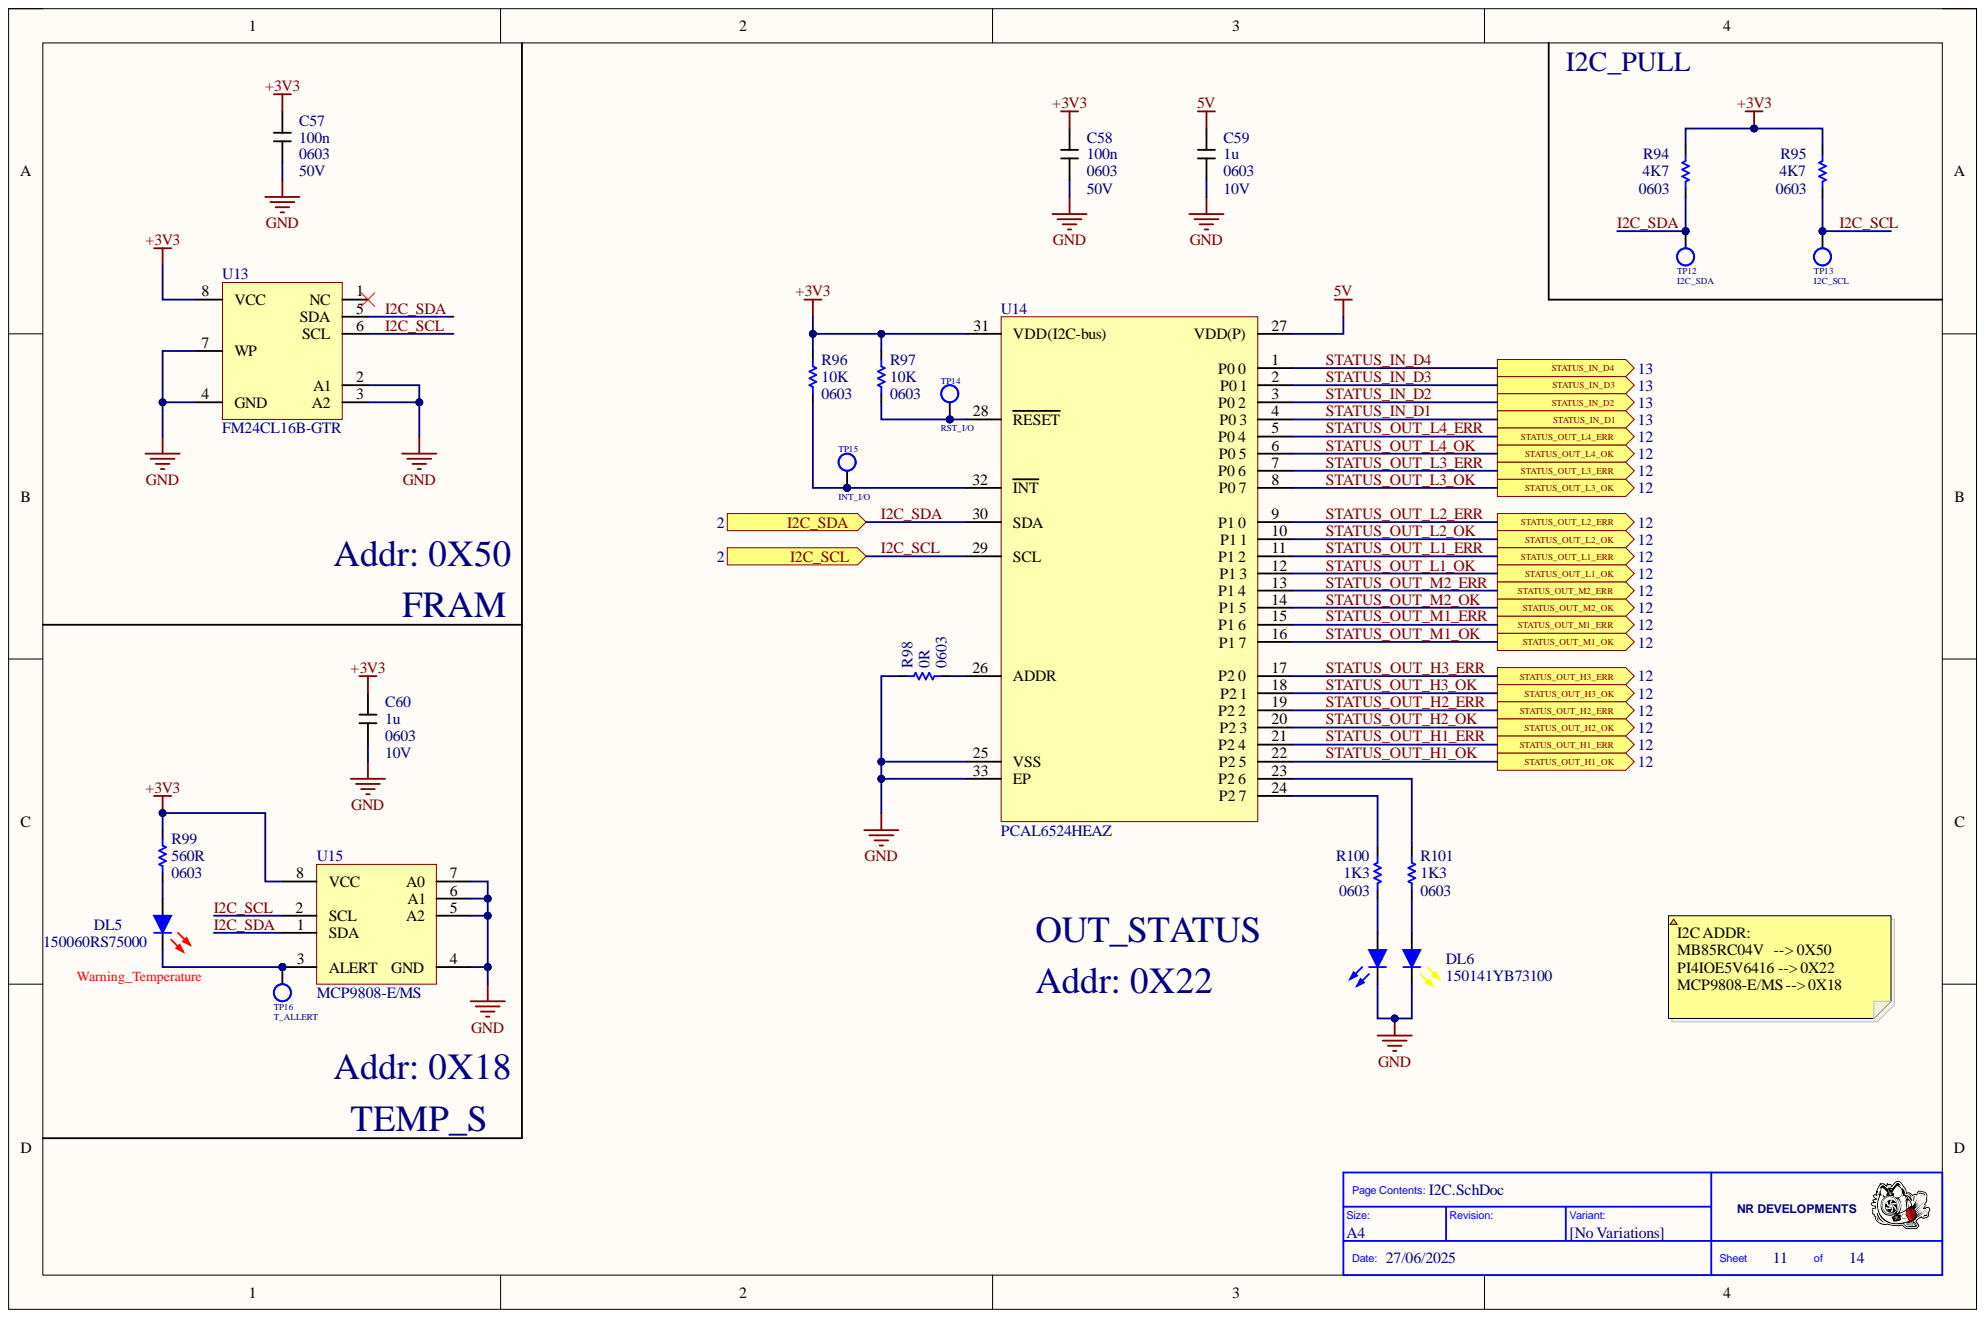
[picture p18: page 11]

Page Contents: I2C . S c hD o c | N R D E V E L O P M E N T S

Size : A4 | Revision : | Variant : [No Va riation s ]

Date : 27/06/20 2 5 | Shee t 1 1 of 14

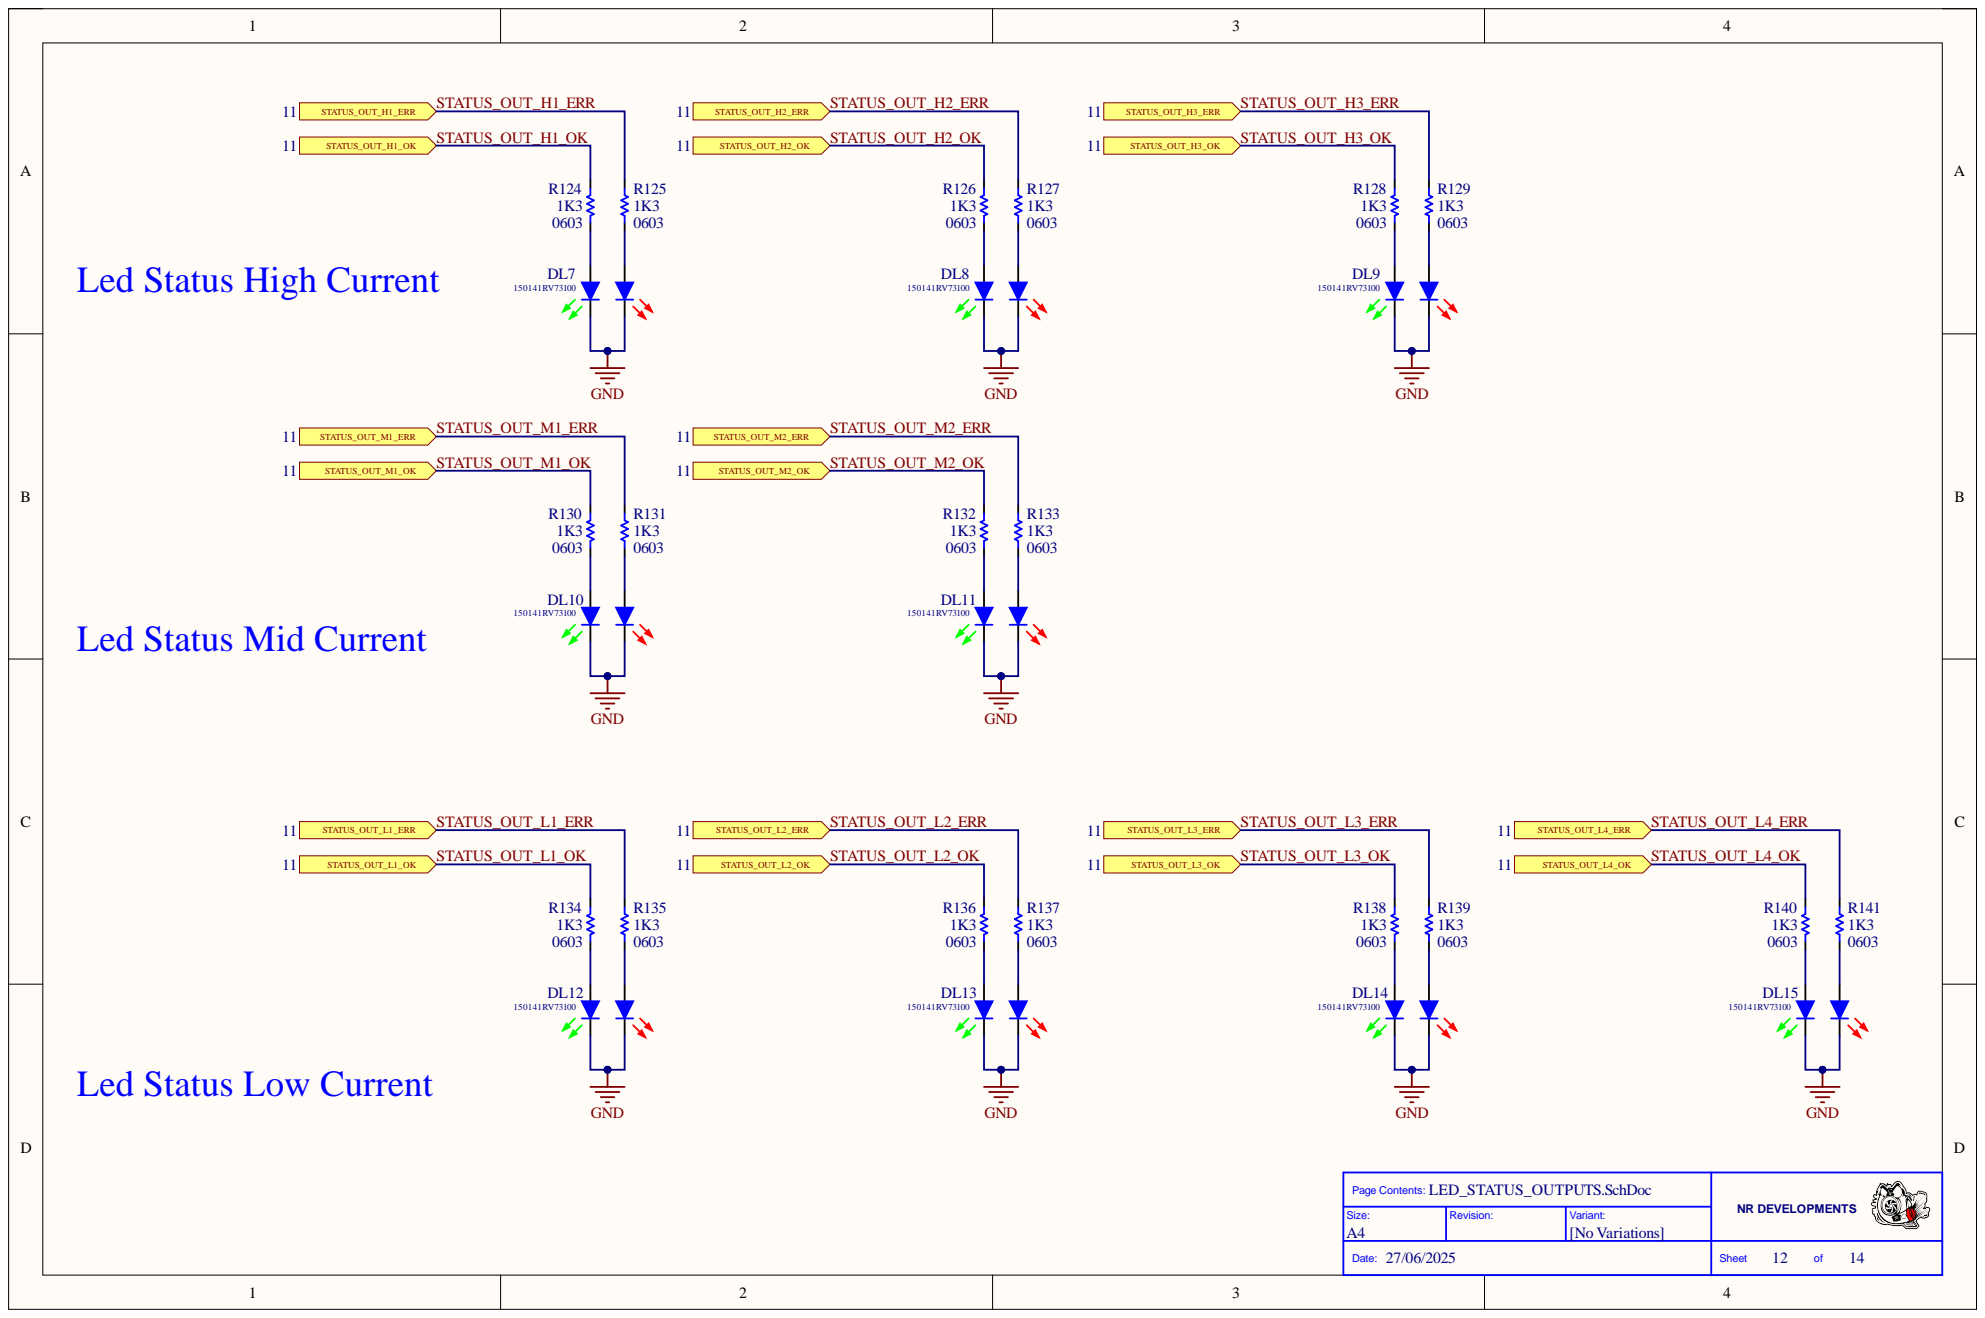
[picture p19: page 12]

Led Status High Current

Led Status Mid Current

Led Status Low Current

Page Contents: LED_STATUS_OUTPUTS.SchDoc

Size: A4 | Revision: | [No Variations] | NR DEVELOPMENTS Variant:

Date: 27/06/2025 | Sheet 12 of 14


Led Status Logic Input

Page Contents: LED_STATUS_INPUT.SchDoc

Size: A4 | Revision: | [No Variations] | NR DEVELOPMENTS Variant:

Date: 27/06/2025 | Sheet 13 of 14


Page Contents: CONNECTOR.SchDoc

Size: A4 | Revision: | [No Variations] | NR DEVELOPMENTS Variant:

Date: 27/06/2025 | Sheet 14 of 14



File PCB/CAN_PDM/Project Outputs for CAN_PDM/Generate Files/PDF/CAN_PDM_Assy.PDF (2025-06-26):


View from Top side (Scale 2:1)



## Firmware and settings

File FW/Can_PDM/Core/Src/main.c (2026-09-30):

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
/* Includes ------------------------------------------------------------------*/
#include "main.h"
#include "cmsis_os.h"
#include "adc.h"
#include "can.h"
#include "dma.h"
#include "i2c.h"
#include "usb_device.h"
#include "gpio.h"

/* USER CODE BEGIN Includes */
#include "keypad_manager.h"
#include "mcp9808.h"
#include "io_expander.h"
/* USER CODE END Includes */


void SystemClock_Config(void);
void MX_FREERTOS_Init(void);
/**
  * @brief  The application entry point.
  * @retval int
  */
int main(void)
{

  /* MCU Configuration--------------------------------------------------------*/

  /* Reset of all peripherals, Initializes the Flash interface and the Systick. */
  HAL_Init();

  /* Configure the system clock */
  SystemClock_Config();

  /* Initialize all configured peripherals */
  MX_GPIO_Init();
  MX_DMA_Init();
  MX_ADC1_Init();
  MX_CAN1_Init();
  MX_I2C1_Init();
  /* USER CODE BEGIN 2 */
  HAL_ADC_Start_DMA(&hadc1, (uint32_t*)adcRaw, 12);
  CAN_Manager_Init();
  Keypad_Init();
  IOExpander_Init();
  MCP9808_Init(MCP9808_UPPER_TEMP_LIMIT, MCP9808_CRITICAL_TEMP_LIMIT); //Init mcp9808 and set limit temp for alert led


  /* USER CODE END 2 */

  /* Call init function for freertos objects (in cmsis_os2.c) */
  MX_FREERTOS_Init();

  /* Start scheduler */
  osKernelStart();

  /* We should never get here as control is now taken by the scheduler */

  /* Infinite loop */
  /* USER CODE BEGIN WHILE */
  while (1)
  {
    /* USER CODE END WHILE */

    /* USER CODE BEGIN 3 */
  }
  /* USER CODE END 3 */
}

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
/**
  * @brief  Period elapsed callback in non blocking mode
  * @note   This function is called  when TIM6 interrupt took place, inside
  * HAL_TIM_IRQHandler(). It makes a direct call to HAL_IncTick() to increment
  * a global variable "uwTick" used as application time base.
  * @param  htim : TIM handle
  * @retval None
  */
void HAL_TIM_PeriodElapsedCallback(TIM_HandleTypeDef *htim)
{
  if (htim->Instance == TIM6)
  {
    HAL_IncTick();
  }
}

/**
  * @brief  This function is executed in case of error occurrence.
  * @retval None
  */
void Error_Handler(void)
{
  /* USER CODE BEGIN Error_Handler_Debug */
  /* User can add his own implementation to report the HAL error return state */
  __disable_irq();
  while (1)
  {
  }
  /* USER CODE END Error_Handler_Debug */
}
#ifdef USE_FULL_ASSERT
/**
  * @brief  Reports the name of the source file and the source line number
  *         where the assert_param error has occurred.
  * @param  file: pointer to the source file name
  * @param  line: assert_param error line source number
  * @retval None
  */
void assert_failed(uint8_t *file, uint32_t line)
{
  /* USER CODE BEGIN 6 */
  /* User can add his own implementation to report the file name and line number,
     ex: printf("Wrong parameters value: file %s on line %d\r\n", file, line) */
  /* USER CODE END 6 */
}
#endif /* USE_FULL_ASSERT */

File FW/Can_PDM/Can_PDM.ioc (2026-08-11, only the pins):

Mcu.UserName=STM32F446RETx
PA0-WKUP.GPIO_Label=PDM_IS_L1_2
PA0-WKUP.Signal=ADCx_IN0
PA1.GPIO_Label=PDM_IS_L3_4
PA1.Signal=ADCx_IN1
PA11.Signal=USB_OTG_FS_DM
PA12.Signal=USB_OTG_FS_DP
PA13.Signal=SYS_JTMS-SWDIO
PA14.Signal=SYS_JTCK-SWCLK
PA15.GPIO_Label=PDM_DIG_IN1
PA15.Signal=GPIO_Input
PA2.GPIO_Label=PDM_IS_M2
PA2.Signal=ADCx_IN2
PA3.GPIO_Label=PDM_BATTERY_SENSE
PA3.Signal=ADCx_IN3
PA4.GPIO_Label=PDM_IS_M1
PA4.Signal=ADCx_IN4
PA5.GPIO_Label=PDM_IS_H3
PA5.Signal=ADCx_IN5
PA6.GPIO_Label=PDM_IS_H2
PA6.Signal=ADCx_IN6
PA7.GPIO_Label=PDM_IS_H1
PA7.Signal=ADCx_IN7
PA8.GPIO_Label=PDM_L_DSEL3_4
PA8.Signal=GPIO_Output
PA9.Signal=USB_OTG_FS_VBUS
PB0.GPIO_Label=PDM_L_OUT2_EN
PB0.Signal=GPIO_Output
PB1.GPIO_Label=PDM_L_DSEL1_2
PB1.Signal=GPIO_Output
PB10.GPIO_Label=PDM_L_OUT3_EN
PB10.Signal=GPIO_Output
PB12.GPIO_Label=PDM_LED_CAN_TX
PB12.Signal=GPIO_Output
PB13.GPIO_Label=PDM_LED_CAN_RX
PB13.Signal=GPIO_Output
PB14.GPIO_Label=PDM_H_OUT1_EN
PB14.Signal=GPIO_Output
PB15.GPIO_Label=PDM_H_OUT2_EN
PB15.Signal=GPIO_Output
PB2.GPIO_Label=PDM_L_OUT1_EN
PB2.Signal=GPIO_Output
PB3.Signal=SYS_JTDO-SWO
PB6.Signal=I2C1_SCL
PB7.Signal=I2C1_SDA
PB8.Signal=CAN1_RX
PB9.Signal=CAN1_TX
PC0.GPIO_Label=PDM_AN_IN1
PC0.Signal=ADCx_IN10
PC1.GPIO_Label=PDM_AN_IN2
PC1.Signal=ADCx_IN11
PC10.GPIO_Label=PDM_DIG_IN2
PC10.Signal=GPIO_Input
PC11.GPIO_Label=PDM_DIG_IN3
PC11.Signal=GPIO_Input
PC12.GPIO_Label=PDM_DIG_IN4
PC12.Signal=GPIO_Input
PC2.GPIO_Label=PDM_AN_IN3
PC2.Signal=ADCx_IN12
PC3.GPIO_Label=PDM_AN_IN4
PC3.Signal=ADCx_IN13
PC6.GPIO_Label=PDM_H_OUT3_EN
PC6.Signal=GPIO_Output
PC7.GPIO_Label=PDM_M_OUT1_EN
PC7.Signal=GPIO_Output
PC8.GPIO_Label=PDM_M_OUT2_EN
PC8.Signal=GPIO_Output
PC9.GPIO_Label=PDM_L_OUT4_EN
PC9.Signal=GPIO_Output
PD2.GPIO_Label=PDM_STATUS
PD2.Signal=GPIO_Output
PH0-OSC_IN.Signal=RCC_OSC_IN
PH1-OSC_OUT.Signal=RCC_OSC_OUT

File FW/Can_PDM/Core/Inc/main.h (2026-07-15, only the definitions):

#define PDM_AN_IN1_Pin GPIO_PIN_0
#define PDM_AN_IN1_GPIO_Port GPIOC
#define PDM_AN_IN2_Pin GPIO_PIN_1
#define PDM_AN_IN2_GPIO_Port GPIOC
#define PDM_AN_IN3_Pin GPIO_PIN_2
#define PDM_AN_IN3_GPIO_Port GPIOC
#define PDM_AN_IN4_Pin GPIO_PIN_3
#define PDM_AN_IN4_GPIO_Port GPIOC
#define PDM_IS_L1_2_Pin GPIO_PIN_0
#define PDM_IS_L1_2_GPIO_Port GPIOA
#define PDM_IS_L3_4_Pin GPIO_PIN_1
#define PDM_IS_L3_4_GPIO_Port GPIOA
#define PDM_IS_M2_Pin GPIO_PIN_2
#define PDM_IS_M2_GPIO_Port GPIOA
#define PDM_BATTERY_SENSE_Pin GPIO_PIN_3
#define PDM_BATTERY_SENSE_GPIO_Port GPIOA
#define PDM_IS_M1_Pin GPIO_PIN_4
#define PDM_IS_M1_GPIO_Port GPIOA
#define PDM_IS_H3_Pin GPIO_PIN_5
#define PDM_IS_H3_GPIO_Port GPIOA
#define PDM_IS_H2_Pin GPIO_PIN_6
#define PDM_IS_H2_GPIO_Port GPIOA
#define PDM_IS_H1_Pin GPIO_PIN_7
#define PDM_IS_H1_GPIO_Port GPIOA
#define PDM_L_OUT2_EN_Pin GPIO_PIN_0
#define PDM_L_OUT2_EN_GPIO_Port GPIOB
#define PDM_L_DSEL1_2_Pin GPIO_PIN_1
#define PDM_L_DSEL1_2_GPIO_Port GPIOB
#define PDM_L_OUT1_EN_Pin GPIO_PIN_2
#define PDM_L_OUT1_EN_GPIO_Port GPIOB
#define PDM_L_OUT3_EN_Pin GPIO_PIN_10
#define PDM_L_OUT3_EN_GPIO_Port GPIOB
#define PDM_LED_CAN_TX_Pin GPIO_PIN_12
#define PDM_LED_CAN_TX_GPIO_Port GPIOB
#define PDM_LED_CAN_RX_Pin GPIO_PIN_13
#define PDM_LED_CAN_RX_GPIO_Port GPIOB
#define PDM_H_OUT1_EN_Pin GPIO_PIN_14
#define PDM_H_OUT1_EN_GPIO_Port GPIOB
#define PDM_H_OUT2_EN_Pin GPIO_PIN_15
#define PDM_H_OUT2_EN_GPIO_Port GPIOB
#define PDM_H_OUT3_EN_Pin GPIO_PIN_6
#define PDM_H_OUT3_EN_GPIO_Port GPIOC
#define PDM_M_OUT1_EN_Pin GPIO_PIN_7
#define PDM_M_OUT1_EN_GPIO_Port GPIOC
#define PDM_M_OUT2_EN_Pin GPIO_PIN_8
#define PDM_M_OUT2_EN_GPIO_Port GPIOC
#define PDM_L_OUT4_EN_Pin GPIO_PIN_9
#define PDM_L_OUT4_EN_GPIO_Port GPIOC
#define PDM_L_DSEL3_4_Pin GPIO_PIN_8
#define PDM_L_DSEL3_4_GPIO_Port GPIOA
#define PDM_DIG_IN1_Pin GPIO_PIN_15
#define PDM_DIG_IN1_GPIO_Port GPIOA
#define PDM_DIG_IN2_Pin GPIO_PIN_10
#define PDM_DIG_IN2_GPIO_Port GPIOC
#define PDM_DIG_IN3_Pin GPIO_PIN_11
#define PDM_DIG_IN3_GPIO_Port GPIOC
#define PDM_DIG_IN4_Pin GPIO_PIN_12
#define PDM_DIG_IN4_GPIO_Port GPIOC
#define PDM_STATUS_Pin GPIO_PIN_2
#define PDM_STATUS_GPIO_Port GPIOD

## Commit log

2024-10-04 Working on requirments, test fw
    [CAN.SchDoc, CAN_PDM.PrjPcb, I2C.SchDoc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]
2024-10-07 Working on schematics
    [MCU.SchDoc]
2024-11-18 Working on schematic
    [LED_STATUS.SchDoc]
2024-12-19 - Fixed issues in the schematic for better accuracy. - Started working on the PCB design.
    [CAN.SchDoc, CAN_PDM.PcbDoc, CAN_PDM.PrjPcb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]
2025-04-01 Working on pcb design
    [CAN.SchDoc, CAN_PDM_Pcb.PcbDoc, HIGH_CURR_MOS.SchDoc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]
2025-04-22 Working on pcb
    [CAN_PDM_Pcb.PcbDoc, PWR.SchDoc]
2025-05-06 Update pcb
    [CAN_PDM.PrjPcb, CAN_PDM_Pcb.PcbDoc, CONNECTOR.SchDoc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]
2025-05-08 Work on pcb
    [CAN_PDM.PrjPcb, CAN_PDM_Pcb.PcbDoc]
2025-05-08 Finalize PCB layout – pending final review before fabrication
    [CAN_PDM_Pcb.PcbDoc, CONNECTOR.SchDoc, HIGH_CURR_MOS2.SchDoc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]
2025-05-12 Update PCB + add thermal simulations photos
    [CAN_PDM.PrjPcb, CAN_PDM_Pcb.DWG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]
2025-05-27 Update pcb. Change pull-up resistor (sensor input) from 3v3 to 5v, because sensors are 5v inp
    [CAN_PDM.PrjPcb, CAN_PDM_Pcb.PcbDoc, SENSOR_INP.SchDoc]
2025-06-18 Update Docs
    [Bill of Materials-CAN_PDM_Pcb(V1).xlsx, CAN_PDM.PrjPcb, CAN_PDM_Pcb.DWG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]
2025-06-27 Update doc
    [CAN_PDM.PrjPcb, CAN_PDM_Pcb.PcbDoc]
2025-07-03 Performed first power-up of the board after assembly. Verified presence of expected voltages, inspected components and solder joints. Noticed the 5V presence LED was mounted in reverse — fixed the is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
2025-07-15 Implement board status management with getter and setter functions
    - Added functions to set and get the board status using enum BoardStatus_t.
    - Created a FreeRTOS task that reads the board status and blinks the status LED accordingly:
    - BOARD_OK: slow toggle (1s delay)
    - BOARD_KO_CAN: 2 quick blinks
    - BOARD_KO_ADC: 4 quick blinks
    - BOARD_KO_I2C: 6 quick blinks
    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
2025-07-28 Test with current read of profet
2025-08-12 Fw test on car (easyeasy)
    [BOX.step, BusBar.step, Cover.stl]
2026-07-15 Re-create firmware.
    [CAN_PDM_CAN_Msg.xlsx]
2026-08-11 Improve PROFET fault monitoring and PDM configuration - Monitor current faults only when the output is enabled - Prevent false fault detection while outputs are OFF - Add configurable PDM identificat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
    [Can_PDM.ioc, keypad_manager.c, main.c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]
2026-09-10 Change Start-up current for test
2026-09-30 Update readme, update docs
    [Assorbimenti.xlsx, Bill of Materials-CAN_PDM(V1).xlsx, CAN_PDM_CAN_Msg.xlsx]

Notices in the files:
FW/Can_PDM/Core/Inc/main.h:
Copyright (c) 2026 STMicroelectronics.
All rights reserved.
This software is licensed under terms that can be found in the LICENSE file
